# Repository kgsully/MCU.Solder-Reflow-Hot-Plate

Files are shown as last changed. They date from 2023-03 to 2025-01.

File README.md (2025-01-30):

# Solder Reflow Hot Plate
 ATMEGA328P-AU Based Solder Reflow Hot Plate Design.

 Please refer to the README docx or PDF found in the documentation folder for further information.
 
 Schematics and drawings may be found within the documentation folder (dimensions are in mm). 
 
 3D design / printing models are located under the 'Enclosure' folder.

 Imgur

 Imgur

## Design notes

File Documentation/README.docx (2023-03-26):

Solder Reflow Hot Plate

Rev 1.1

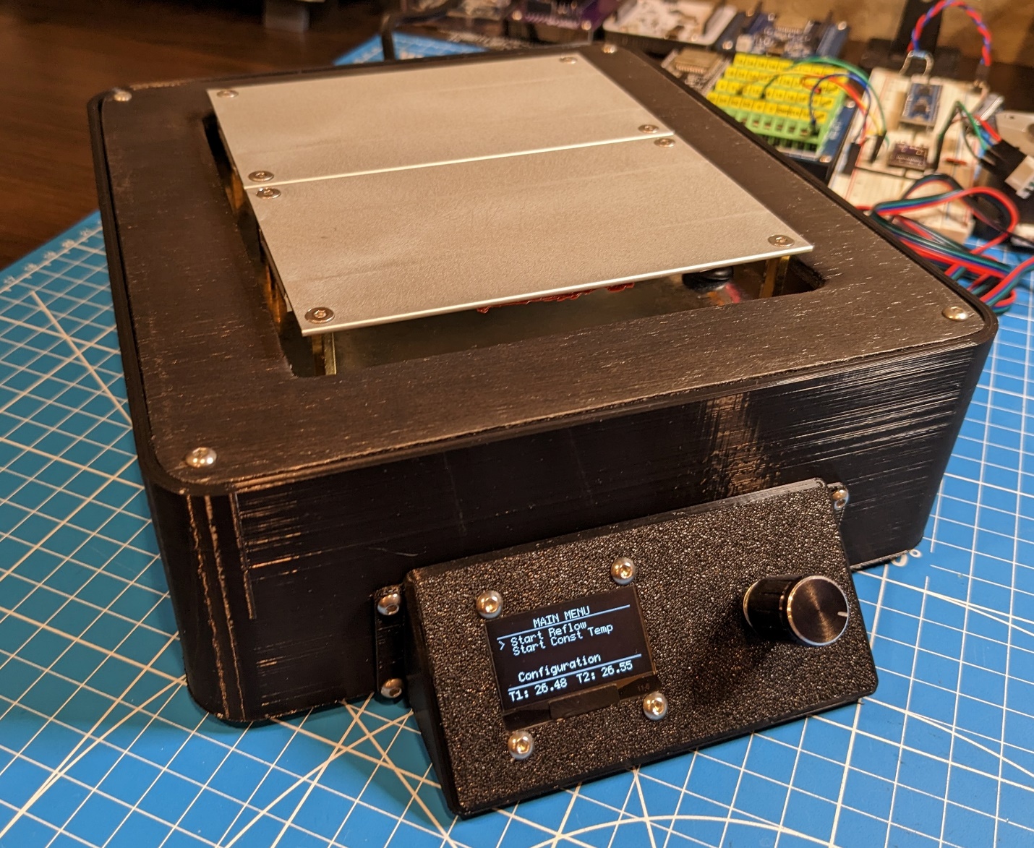
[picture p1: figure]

Ken S. 03/2023

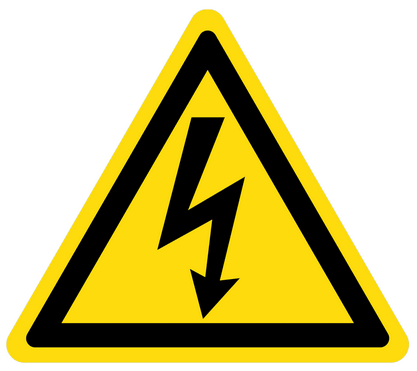
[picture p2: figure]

DANGER!

This project uses mains voltage to power portions of the circuit and the heating elements in the hot plates. This represents an electric shock hazard that can cause serious injury or death. Take appropriate care and do not attempt if you are not comfortable with or qualified to work with mains voltage.

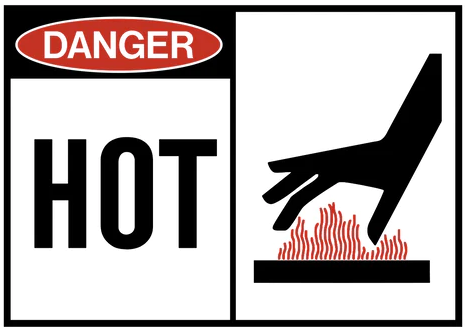
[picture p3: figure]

DANGER!

The heating plates used in this project can exceed 200°C and present burn and fire risks.

# 1. Description

This is an ATMEGA328P-AU based design for a solder reflow hot plate to be used for soldering SMD components onto custom PCBs. The microcontroller uses 2 PID loops to individually control the temperature for 2 aluminum heating plates. An OLED display and rotary encoder with push button allow the user to configure various parameters (reflow profile, PID tuning constants for the hot plate PID loops, etc), save the configuration to the microcontroller EEPROM memory, and start the unit in either constant temperature mode, or reflow profile mode.

Design files are included for the following:

1. Controller Electrical Schematic (w/ manufacturer and P/N component properties)
2. Controller PCB Layout
3. Interactive PCB Bill of Materials (BOM) – HTML format
4. Arduino IDE & PlatformIO based code
5. 3D Printed Enclosure
6. Sheet metal hot plate base
7. Wood cover plate

# 2. Electrical / PCB

The controller PCB uses zero crossing optocouplers / TRIACs to convert the PWM outputs from the microcontroller and regulate the input AC power used to drive the hot plates to a specified setpoint temperature.

A DIP socket is suggested to be used between the Optocoupler TRIACS (U10 & U20) and the PCB. This is not listed as an item in the BOM.

Please note that the following fuses are required, but not listed –

1. QTY 1 – 5x20mm 1A Time Delay Fuse (for AC / DC Converter)
2. QTY 2 – 5x20mm 4A Fast Acting Fuse (1 for each hot plate output, assumes 120VAC, amperage will need to be changed for 240VAC)

This design uses a Cypress / Infineon CY7C65213-28PVXI USB – UART bridge IC. The newer CY7C65213A-28PVXI may be used in its place. Please use the configuration utility that can be found at the following URL along with the included configuration file to program the USB – UART bridge:

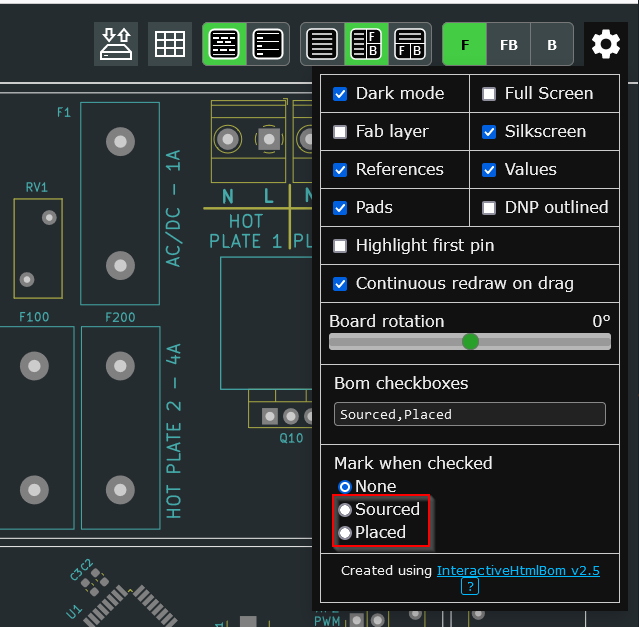
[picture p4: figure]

https://www.infineon.com/cms/en/design-support/tools/configuration/usb-uart-config-utility/

Please refer to the included electrical schematic / PCB design / interactive BOM (html format) for further details. Note that selection of one of the options shown in the screenshot of the interactive BOM may be helpful during PCB assembly –

Completed PCB Pictures:

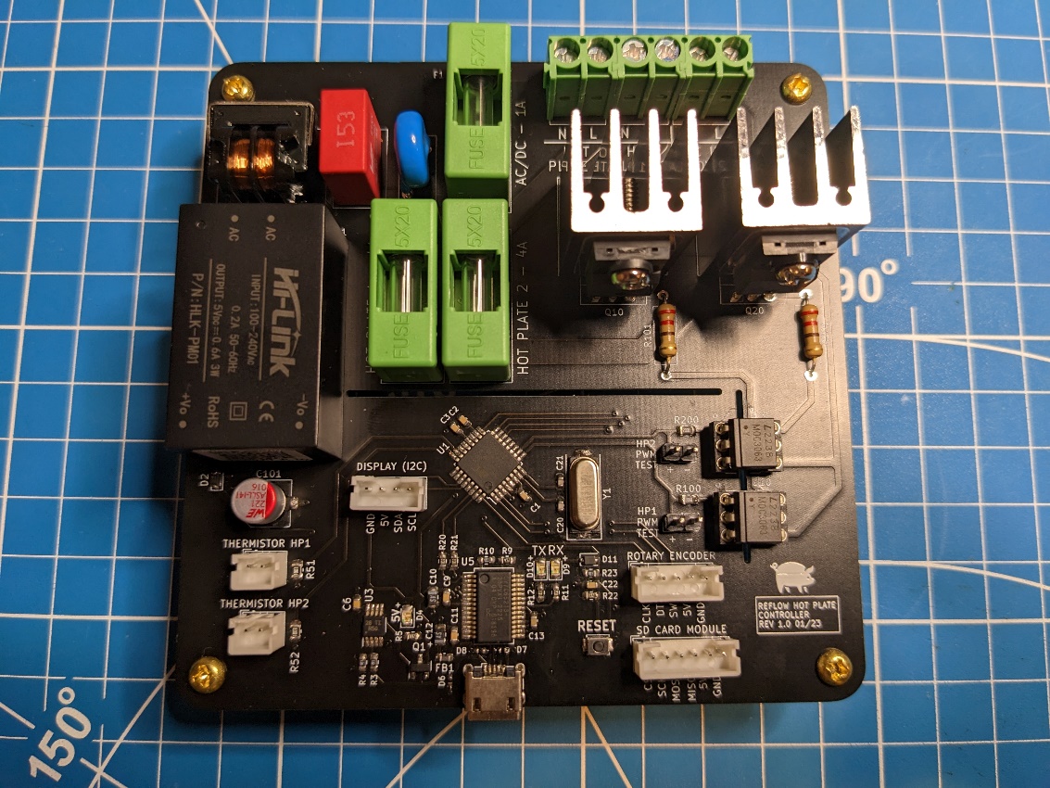
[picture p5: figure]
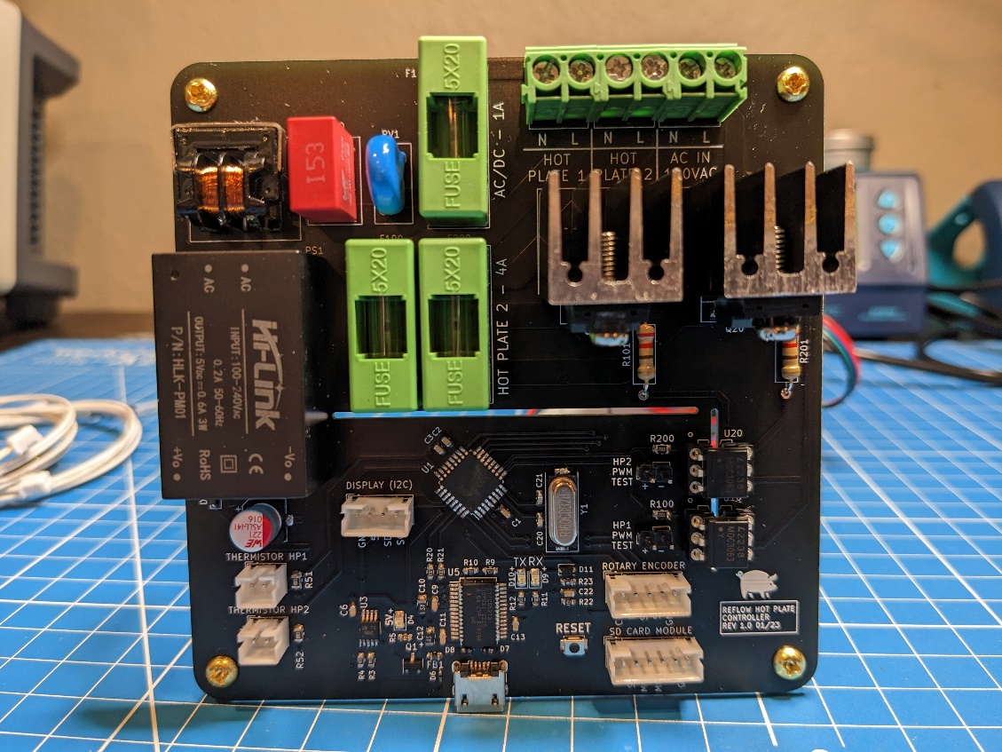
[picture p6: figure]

# 3. Assembly / Construction

Please refer to the included design files for assembly / construction details. Various format 3D models (STEP, F3D, and STL) are included, along with assembly drawings, and detail drawings for non-3D printed enclosure components.

IMPORTANT: Attach ground terminal / lead from AC receptacle so that it has electrical conductivity with hot plates! This is a REQUIRED safety measure to prevent electrical shock.

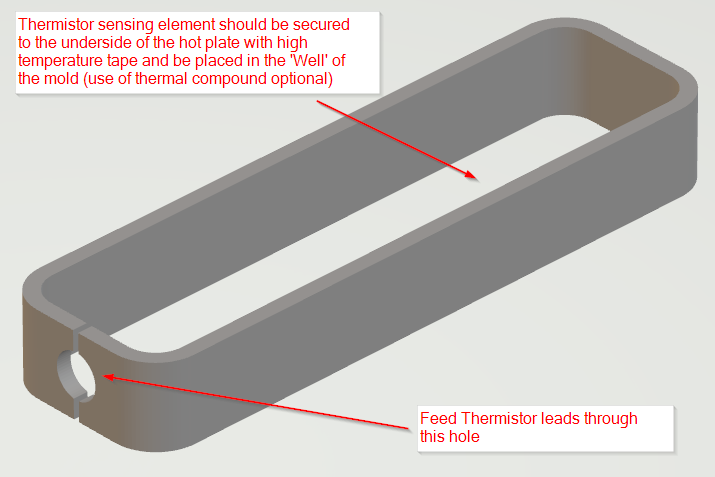
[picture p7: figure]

NOTE: The ‘Thermistor Silicon Mold’ model can be 3D printed and used as an aid to secure the thermistors to the underside of the heating plates.

Thermal compound can be applied to the underside of the hot plate and the thermistor sensing element set inside of it. High temperature tape is then used to secure the thermistor to the plate. Excess tape should be cut away. The ‘Thermistor Silicon Mold’ can then be set in place and be temporarily secured so that high temperature silicon may be applied to fill the mold ‘well’ and ensure the thermistors remain in place.

# 4. Microcontroller Code

Either the Arduino IDE or VS Code / PlatformIO may be used to upload the code to the microcontroller (both variants are included).

The code uses the following libraries:

1. Wire.h – Included in IDE by default
2. EEPROM.h – Included in IDE by default
3. PID_v1.h – PID by Brett Beauregard (v1.1.1)
4. U8g2lib.h – U8g2 by oliver (v2.33.15)

The U8g2lib object is configured in the included code to be used with an SH1106 based 128 x 64 OLED display. If the OLED display being used differs, this object will need to be reconfigured.

The code includes thermistor failure / thermal runaway protection. If either of the thermistors reads < -20°C, or the same measurement is read 3 consecutive times, heating is disabled and a thermistor failure message is presented on the display.

Configured reflow profile parameters and PID tuning constants are read from the microcontroller EEPROM at boot, and can be saved to the EEPROM by user selection of the ‘Save Configuration’ menu option. Note that the first time the controller board boots after the code is uploaded, default values may be present in the EEPROM. If this is the case, please refer to the code for default values for reflow profile / PID tuning parameters. Default reflow profile parameters are applicable to the reflow curve of the solder paste listed in the comments. Default PID tuning constants are a starting point – the PID loops will need to be tuned to the individual components for each build.

In reflow profile heating mode, the code is configured to take an initial snapshot of the hot plate temperatures and ramp the setpoint from the initial snapshot value to the programmed setpoint over the configured time. This is designed to ‘smooth’ the PID response to the heating curve. This can result in some initial lag when the setpoint starts to change, but helps to prevent overshoot / oscillation when compared with a step change in the temperature setpoint. It also allows the temperature to increase according to an implied ramp rate.

In constant temperature heating mode, the user sets the desired setpoint and the system interprets this as a step change.

# 5. Operation / Usage

Use / configuration of the reflow hot plate is achieved by use of the rotary encoder and display menu system. Rotation of the encoder changes the current selection and depressing the encoder knob selects the currently indicated option.

## 5.1. Menus

The currently selected menu item is indicated / denoted by the ‘>’ character appearing at the left of the menu item.

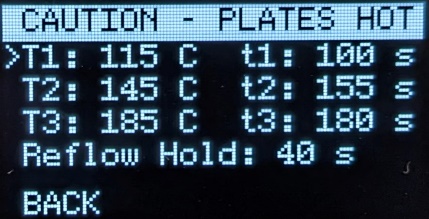
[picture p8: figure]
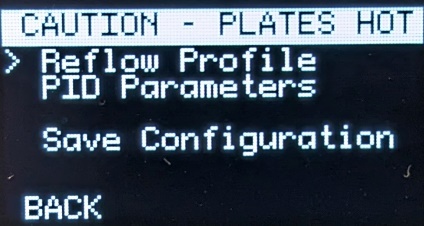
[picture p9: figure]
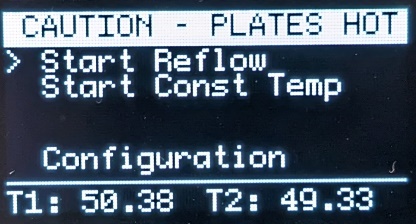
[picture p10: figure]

Note – If either of the hot plate temperatures exceed the programmed setpoint value (40°C), the top banner will change to display a high contrast ‘Caution – Plates Hot’ message.

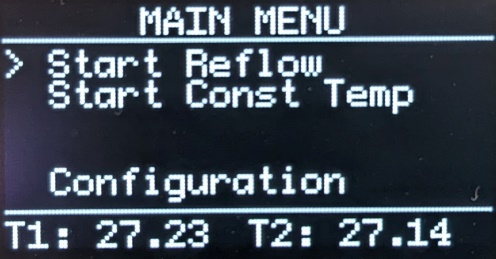
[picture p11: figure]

Main Menu – Used to start Reflow Profile / Constant Temperature heating modes / enter the configuration menu. This menu will also display the current hot plate temperatures at the bottom of the screen.

Start Reflow – Used to start the unit in ‘Reflow Profile’ heating mode. This mode uses the parameters set in the ‘Reflow Profile’ configuration menu and will automatically vary the temperature over time to attempt to coincide with the reflow curve. Upon selection of this menu option, the user is presented with a confirmation to start. The default selection is ‘No’ to prevent unintended start of reflow heating mode.

When reflow heating mode is running, the user is presented with information pertaining to which section of the reflow profile curve the unit is currently in (RAMP, SOAK, REFLOW RAMP, REFLOW, COMPLETE), elapsed time, temperatures of the hot plates (T1 / T2) and the setpoint value (SP).

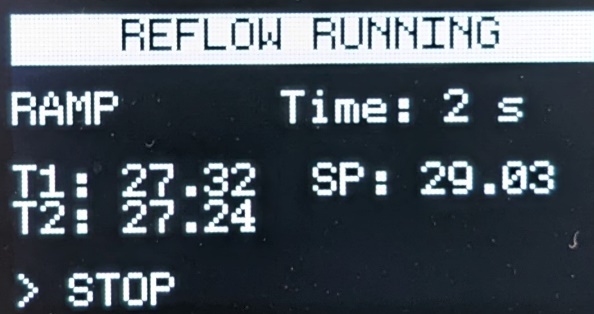
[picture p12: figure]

Selecting stop will prompt the user to confirm stopping the reflow heating mode.

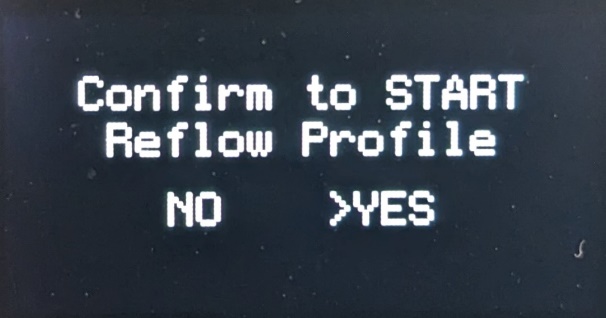
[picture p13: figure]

Start Constant Temp – Used to start the unit in ‘Constant Temperature’ heating mode. In this mode, the unit will heat the hot plates to a single specified temperature setpoint which won’t vary over time. When selected, the user is prompted to confirm start. Upon entering constant temperature heating mode for the first time, the temperature setpoint is set artificially low (default is 35°C) for safety reasons, and the user must select the ‘SP’ menu item, and change to the desired temperature setpoint.

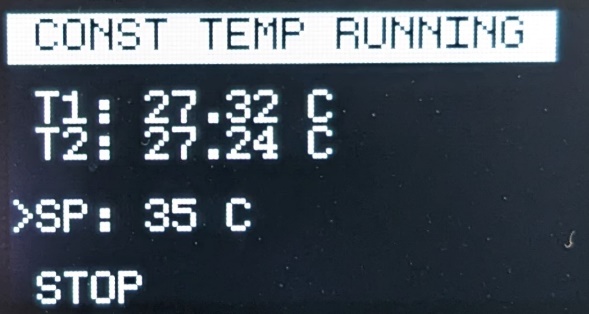
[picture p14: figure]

Selecting stop will prompt the user to confirm stopping the constant temperature heating mode.

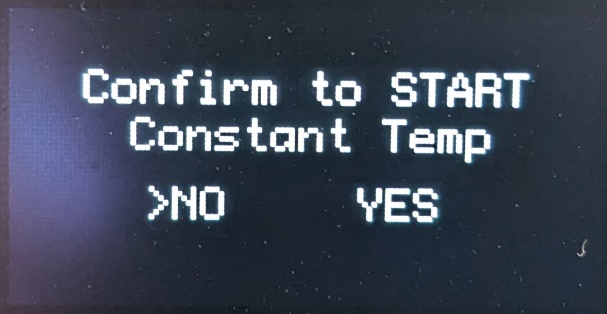
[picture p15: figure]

Configuration Menu – Used to select which configuration parameters to view / modify. The Main menu can be accessed by selecting ‘Back’.

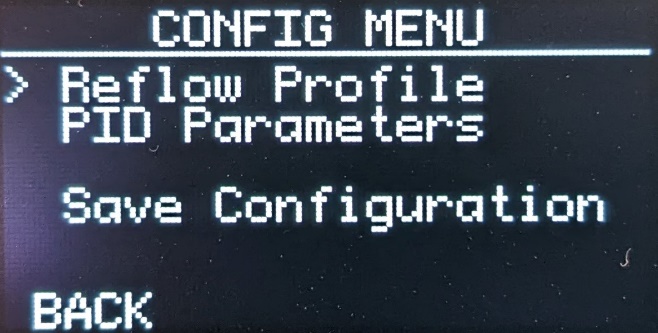
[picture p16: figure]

Reflow Profile – This menu allows the user to configure the reflow heating profile. Temperature setpoints are indicated by ‘uppercase’ T and time setpoints are indicated by ‘lowercase’ t. Selecting a menu item will draw a rectangle around the selected parameter, at which point the value can be changed. Pressing the rotary encoder will set the parameter value.
The Configuration Menu can be accessed by selecting ‘Back’.

Please refer to the following diagram for further explanation regarding reflow profile setpoints. Note that t1 through t3 are times along the X axis of the profile curve, and the reflow hold is a duration.

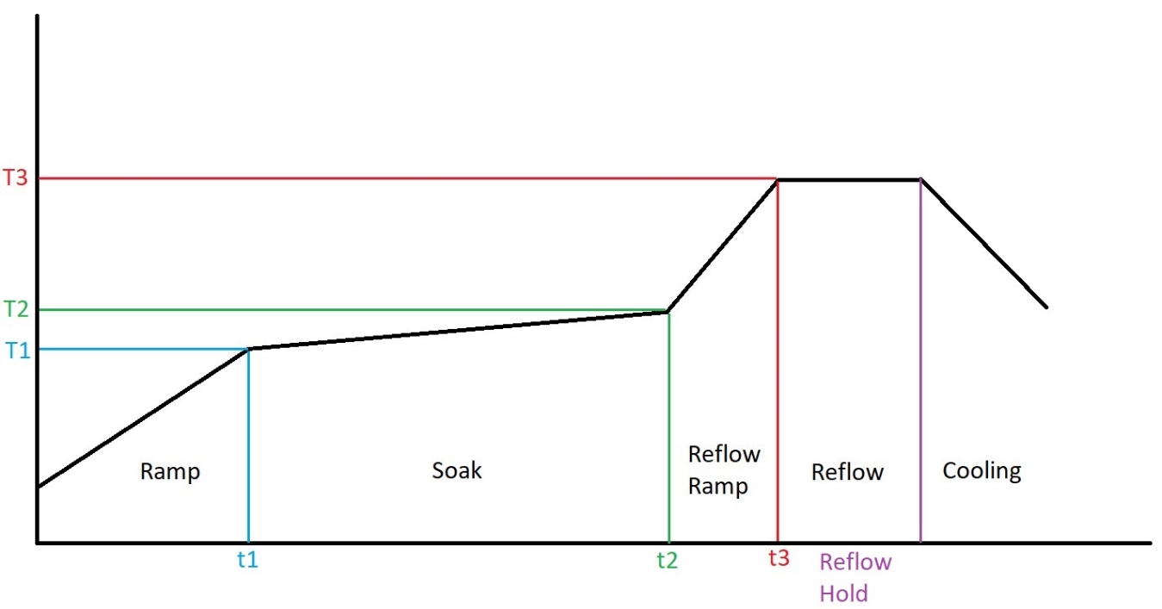
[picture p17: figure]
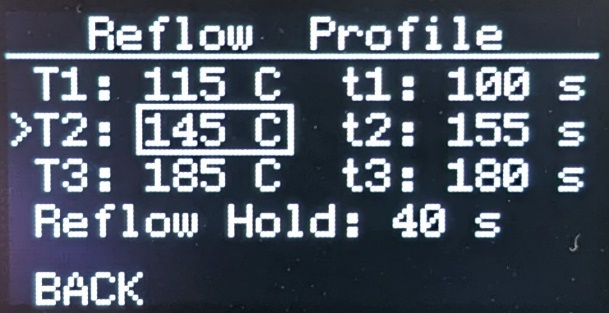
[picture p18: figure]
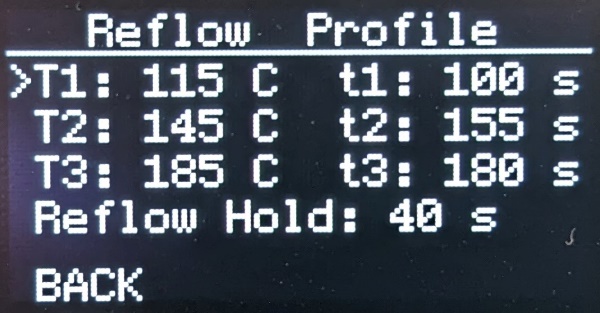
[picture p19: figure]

PID Parameters – This menu allows the user to configure the PID tuning constants for the 2 hot plate PID loops. Selecting a menu item will draw a rectangle around the selected parameter, at which point the value can be changed. Pressing the rotary encoder will set the parameter value.
Default PID tuning constants are intended to be a starting point. The hot plate PID loops will need to be tuned for each individual build as component performance / responses can vary.

The Configuration Menu can be accessed by selecting ‘Back’.

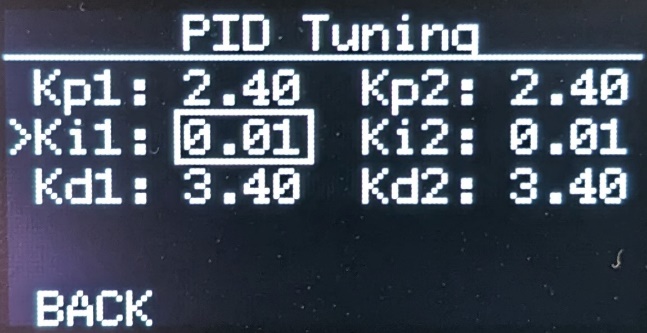
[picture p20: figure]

Save Configuration – Selecting this menu option will write the values of the reflow profile parameters and PID tuning constants to the microcontroller EEPROM. When selected, the user is presented with a message to indicate settings are being saved. Once complete, the display returns to the configuration menu screen.

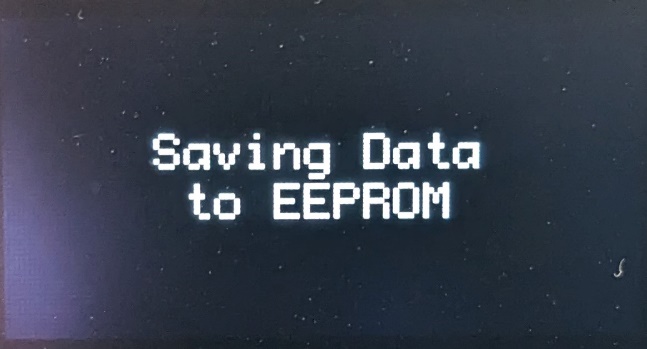
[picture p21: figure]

# 6. Addendum

Links / Part Numbers for various off-board / supporting parts:

AC SOCKET:
250V / 10A, 3 PIN IEC320 C14 MALE
https://www.amazon.com/dp/B0BCYYNRGP?psc=1&ref=ppx_yo2ov_dt_b_product_details

TO-220 TRIAC HEATSINK / HARDWARE:
HEATSINK - RADIOSHACK 2761368
MOUNTING HARDWARE - RADIOSHACK 2761373

HOT PLATES (QTY 2 PLATES REQ'D):
https://www.amazon.com/gp/product/B0BBGCKD5C/ref=ppx_yo_dt_b_search_asin_title?ie=UTF8&psc=1

ROTARY ENCODER MODULE:
https://www.amazon.com/gp/product/B07F26CT6B/ref=ppx_yo_dt_b_search_asin_title?ie=UTF8&psc=1

OLED SCREEN (SSD1106 VERSION):
https://www.amazon.com/gp/product/B08V97FYD2/ref=ppx_yo_dt_b_search_asin_title?ie=UTF8&psc=1

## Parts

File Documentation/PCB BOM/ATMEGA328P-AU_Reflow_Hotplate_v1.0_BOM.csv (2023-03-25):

Id | Designator | Package | Quantity | Designation | Supplier and ref
1 | R10,R4,R3,R23 | R_0603_1608Metric | 4 | 10k
2 | R200,R100 | R_0805_2012Metric | 2 | 200R
3 | F1 | WE 696106003002 | 1 | 1A
4 | C22,C1,C2,C3,C11,C9 | C_0603_1608Metric | 6 | 0.1u
5 | J10,J20 | JST_PH_B2B-PH-K_1x02_P2.00mm_Vertical | 2 | Conn_01x02_Male
6 | U3 | VSSOP-8_3.0x3.0mm_P0.65mm | 1 | LMV358IDGKR
7 | D10,D9 | LED_0805_2012Metric | 2 | GRN
8 | C10,C12 | C_0805_2012Metric | 2 | 4.7u
9 | U5 | SSOP-28_5.3x10.2mm_P0.65mm | 1 | CY7C65213-28PVXI
10 | H4,H2,H1,H3 | MountingHole_3.2mm_M3 | 4 | MountingHole
11 | R101,R201 | R_Axial_DIN0309_L9.0mm_D3.2mm_P12.70mm_Horizontal | 2 | 220R
12 | R11,R22,R5,R12,R21,R20 | R_0603_1608Metric | 6 | 1k
13 | C6 | C_0603_1608Metric | 1 | 100n
14 | C13 | C_0603_1608Metric | 1 | 1u
15 | J502 | JST_PH_B6B-PH-K_1x06_P2.00mm_Vertical | 1 | Conn_01x06_Male
16 | D8,D7,D6 | D_0402_1005Metric | 3 | 5VWM
17 | F100,F200 | WE 696106003002 | 2 | 4A
18 | J100,J200,J300 | TerminalBlock_Phoenix_MKDS-1,5-2_1x02_P5.00mm_Horizontal | 3 | 1935776
19 | C100 | C_Rect_L13.0mm_W8.0mm_P10.00mm_FKS3_FKP3_MKS4 | 1 | 0.1uF
20 | C21,C20 | C_0603_1608Metric | 2 | 22p
21 | J501 | JST_PH_B5B-PH-K_1x05_P2.00mm_Vertical | 1 | Conn_01x05_Male
22 | U20,U10 | DIP-6_W7.62mm | 2 | MOC3063M
23 | D11 | D_SOD-323 | 1 | 1N4148WS
24 | D4 | LED_0805_2012Metric | 1 | RED
25 | FB1 | L_0603_1608Metric | 1 | 40-100R
26 | Q10,Q20 | TO-220-3_Vertical | 2 | BT139X-600,127
27 | U1 | TQFP-32_7x7mm_P0.8mm | 1 | ATmega328P-AU
28 | RV1 | RV_Disc_D12mm_W5.8mm_P7.5mm | 1 | 10D561K
29 | R9 | R_0603_1608Metric | 1 | 4k7
30 | J201,J101 | PinHeader_1x02_P2.54mm_Vertical | 2 | Conn_01x02_Male
31 | R52,R51 | R_0805_2012Metric | 2 | 100k
32 | PS1 | Converter_ACDC_HiLink_HLK-PMxx | 1 | HLK-PM01
33 | FL1 | KEMET SU9H-R02140 | 1 | 14mH
34 | SW1 | SW_SPST_B3U-1000P | 1 | RESET
35 | J3 | USB_Micro-B_Wuerth_629105150521 | 1 | USB_B_Micro
36 | J500 | JST_PH_B4B-PH-K_1x04_P2.00mm_Vertical | 1 | Conn_01x04_Male
37 | Y1 | Crystal_SMD_HC49-SD | 1 | 16MHZ
38 | C101 | CP_Elec_6.3x5.9 | 1 | 220uF
39 | D2 | D_SOD-323 | 1 | BAT760-7
40 | Q1 | SOT-23 | 1 | DMP2110U-7

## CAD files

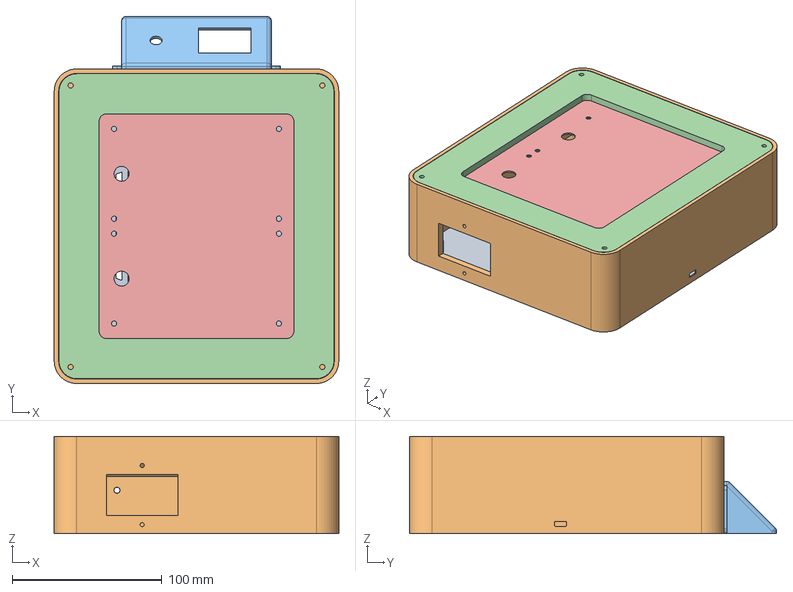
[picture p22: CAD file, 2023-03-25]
Enclosure/Model/Solder Reflow Hot Plate Enclosure Assembly.step
190.0 x 245.0 x 65.0 mm
Solder Reflow Hot Plate Base
Top Cover Plate_1
Hot Plate Mounting Plate_1

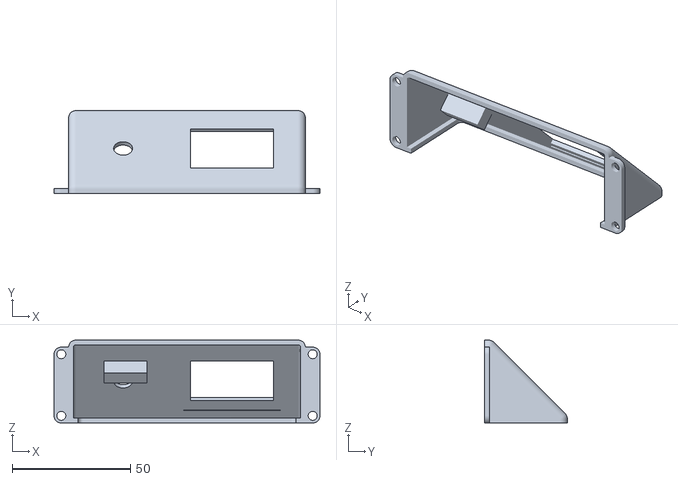
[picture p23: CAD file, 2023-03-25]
Enclosure/3D Printing/Control Enclosure/Model/Control Enclosure.stl
112.4 x 35.0 x 35.0

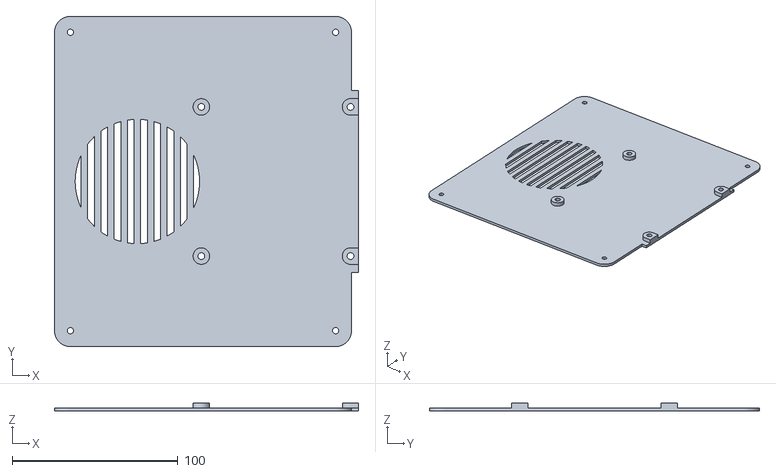
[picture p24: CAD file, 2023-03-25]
Enclosure/3D Printing/Enclosure Base/Model/Board Mount.stl
183.4 x 199.2 x 5.00

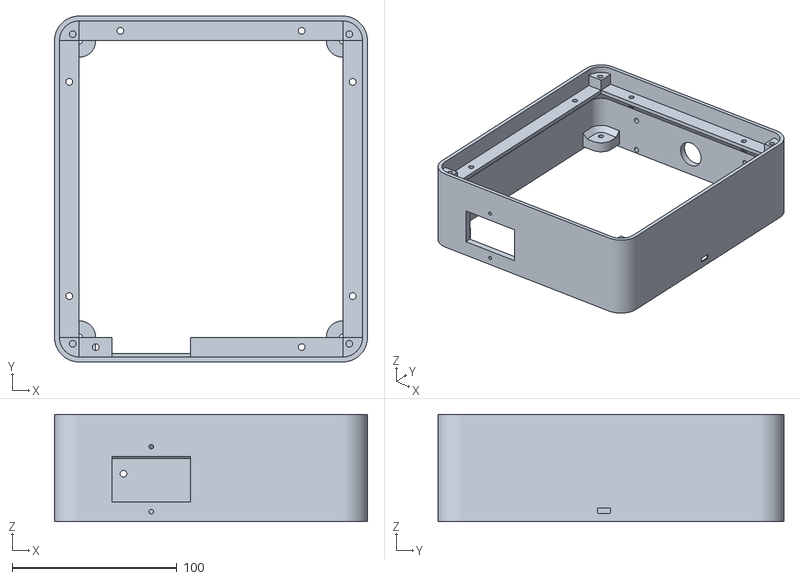
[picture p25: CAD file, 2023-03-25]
Enclosure/3D Printing/Enclosure Side Wall/Model/Sidewall.stl
190.0 x 210.0 x 65.0

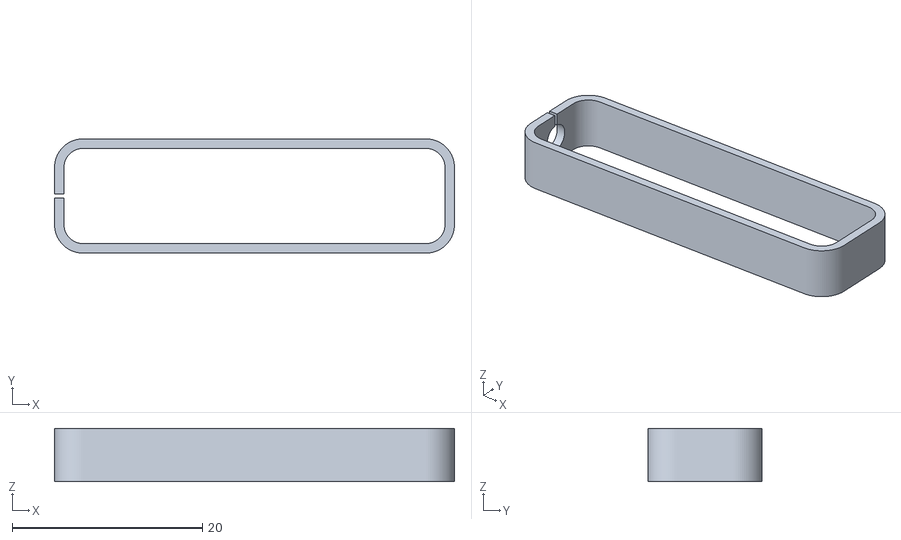
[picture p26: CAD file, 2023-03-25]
Enclosure/3D Printing/Thermistor Silicon Molds/Model/Thermistor SIlicon Mold.stl
42.0 x 12.0 x 5.60

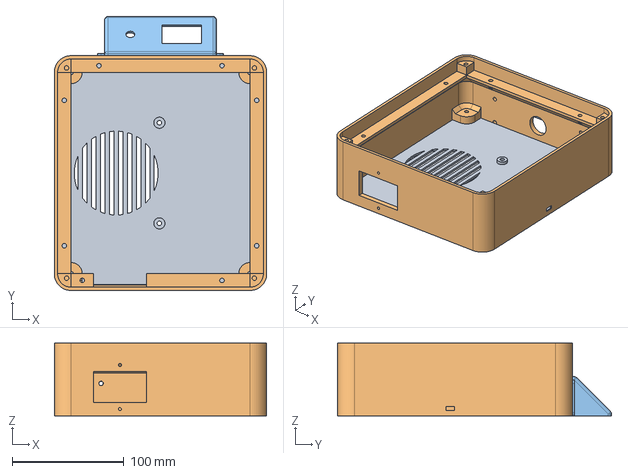
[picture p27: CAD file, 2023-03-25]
Enclosure/Model/Solder Reflow Hot Plate Base.step
190.0 x 245.0 x 65.0 mm

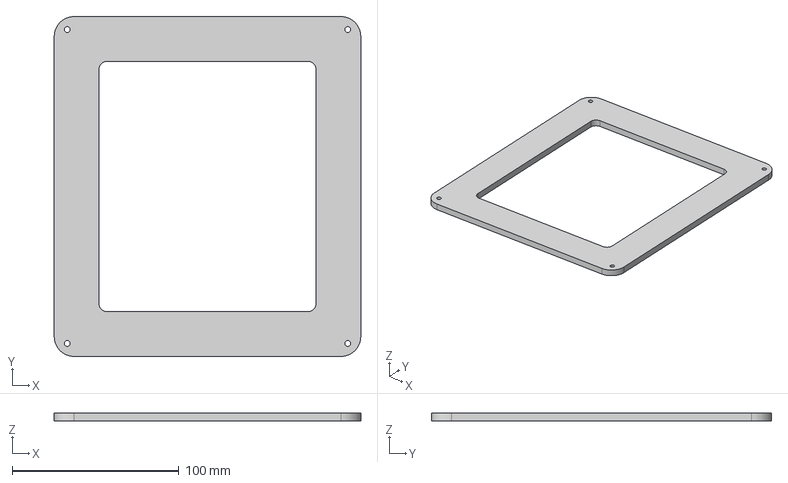
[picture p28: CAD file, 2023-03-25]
Enclosure/Model/Top Cover Plate.step
183.6 x 203.6 x 5.00 mm

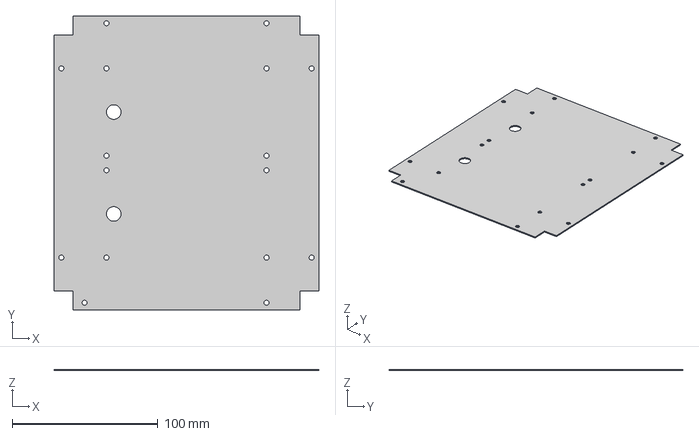
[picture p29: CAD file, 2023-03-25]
Enclosure/Model/Hot Plate Mounting Plate.step
182.0 x 202.0 x 1.00 mm

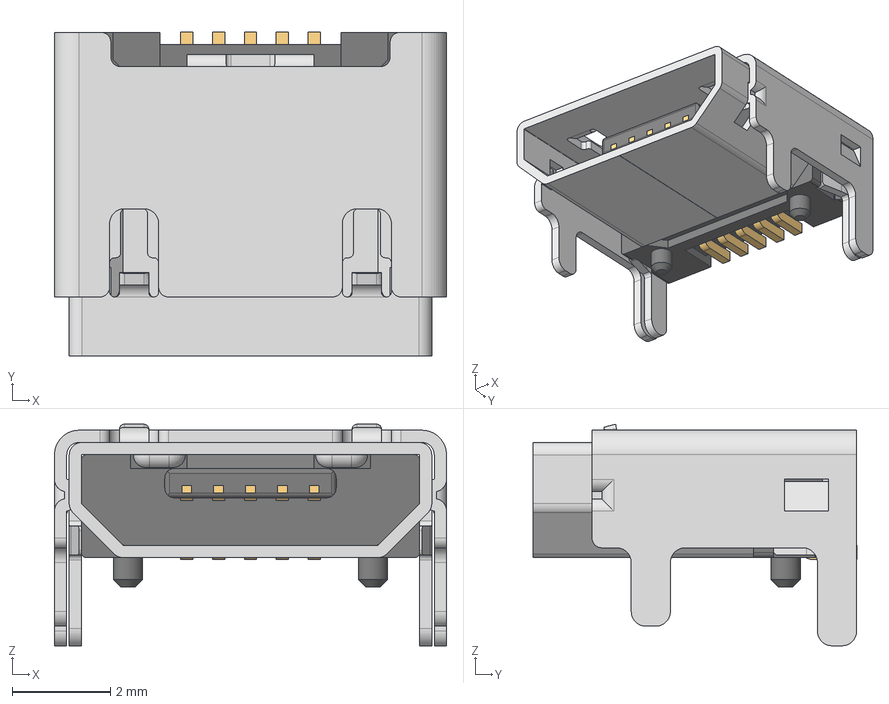
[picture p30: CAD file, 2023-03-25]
Electrical & PCB/Models/629105150521 (rev1).stp
8.00 x 6.60 x 4.52 mm
629105150521_Housing
629105150521_Pin1 x 4
629105150521_Pin2
629105150521_Shielding2
629105150521_Shielding

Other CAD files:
Enclosure/Model/Thermistor Silicon Mold.step
Enclosure/Model/Hot Plate Mounting Plate.f3d
Enclosure/Model/Solder Reflow Hot Plate Base.f3d
Enclosure/Model/Solder Reflow Hot Plate Enclosure Assembly.f3z
Enclosure/Model/Thermistor Silicon Mold.f3d
Enclosure/Model/Top Cover Plate.f3d

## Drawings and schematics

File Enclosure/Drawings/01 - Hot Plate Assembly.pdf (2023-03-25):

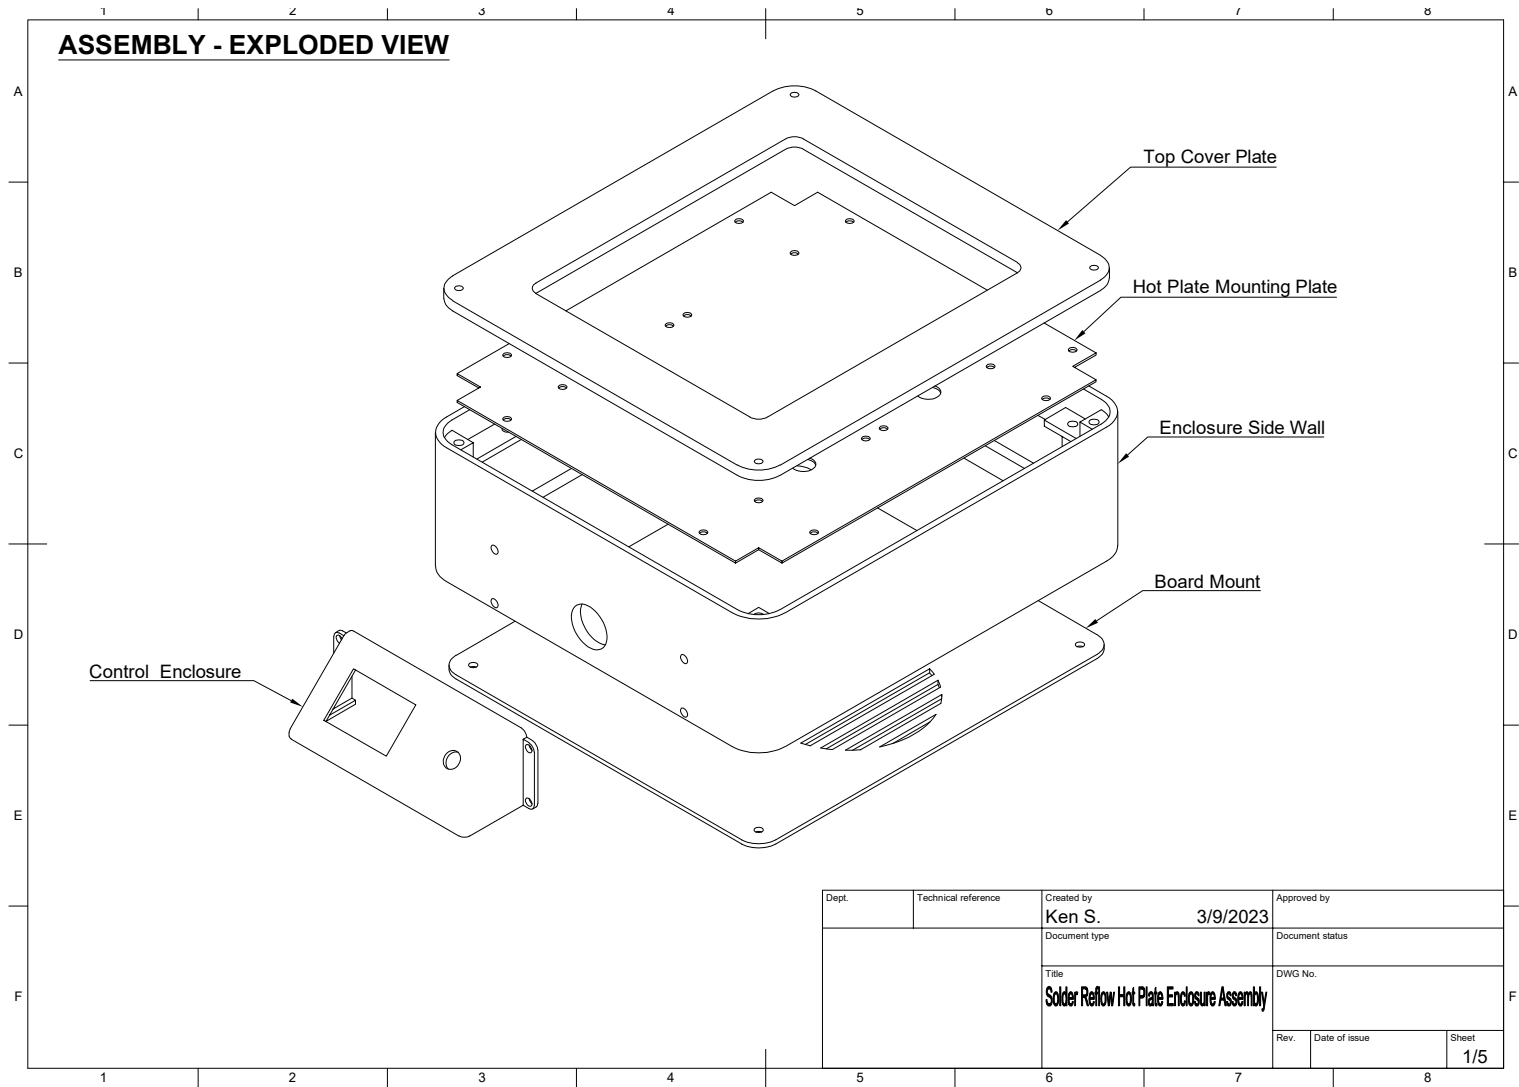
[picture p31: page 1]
8 BCDEF; ABCDEF Dept.; Technical reference; Created by; Approved by Document type; Document status Title; DWG No. Rev.; Date of issue; Sheet 3/9/2023; 1/5 Ken S.; Top Cover Plate Hot Plate Mounting Plate Enclosure Side Wall Control Enclosure; Board Mount ASSEMBLY - EXPLODED VIEW

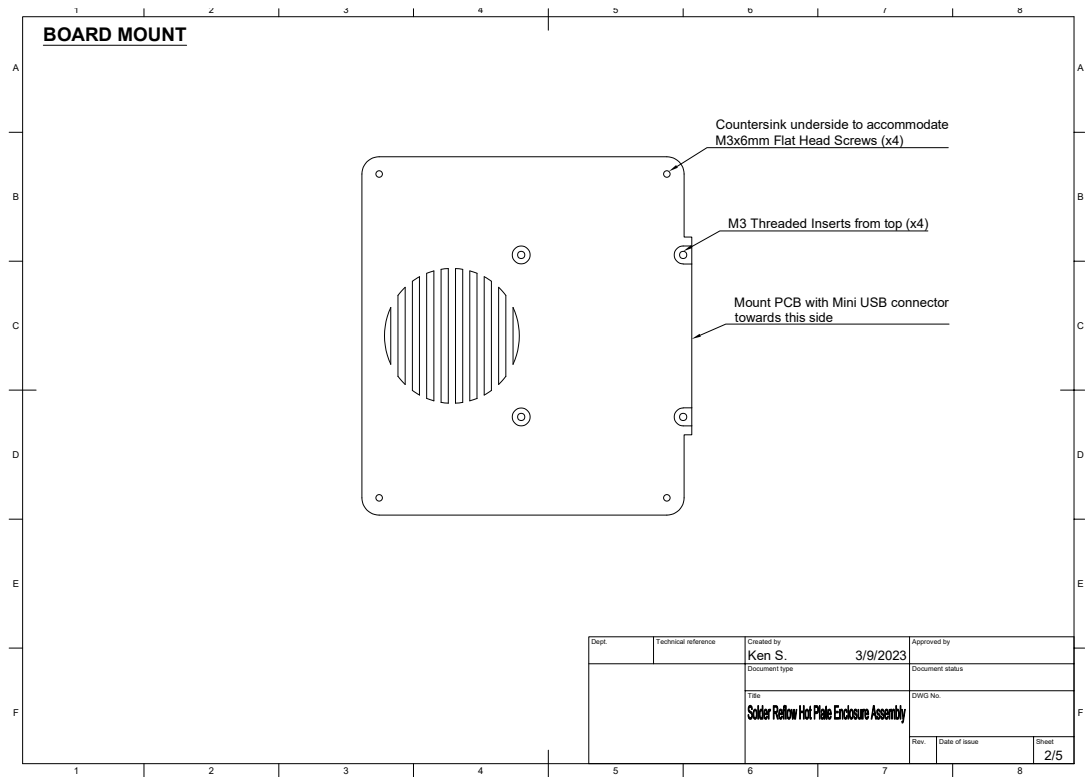
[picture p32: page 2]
8 BCDEF; ABCDEF Dept.; Technical reference; Created by; Approved by Document type; Document status Title; DWG No. Rev.; Date of issue; Sheet 3/9/2023; 2/5 Ken S. M3 Threaded Inserts from top (x4) Countersink underside to accommodate M3x6mm Flat Head Screws (x4) Mount PCB with Mini USB connector towards this side BOARD MOUNT

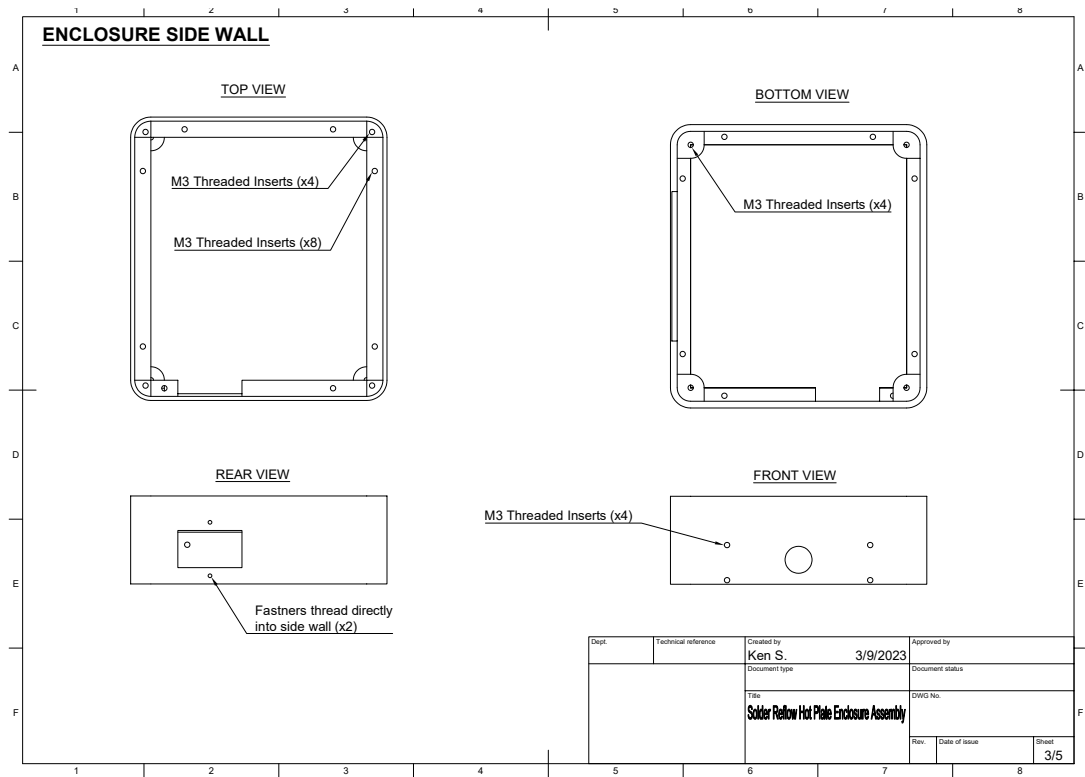
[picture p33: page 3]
8 BCDEF; ABCDEF Dept.; Technical reference; Created by; Approved by Document type; Document status Title; DWG No. Rev.; Date of issue; Sheet 3/9/2023; 3/5 Ken S. TOP VIEW M3 Threaded Inserts (x8) M3 Threaded Inserts (x4); BOTTOM VIEW M3 Threaded Inserts (x4) M3 Threaded Inserts (x4) Fastners thread directly into side wall (x2) REAR VIEW; FRONT VIEW ENCLOSURE SIDE WALL

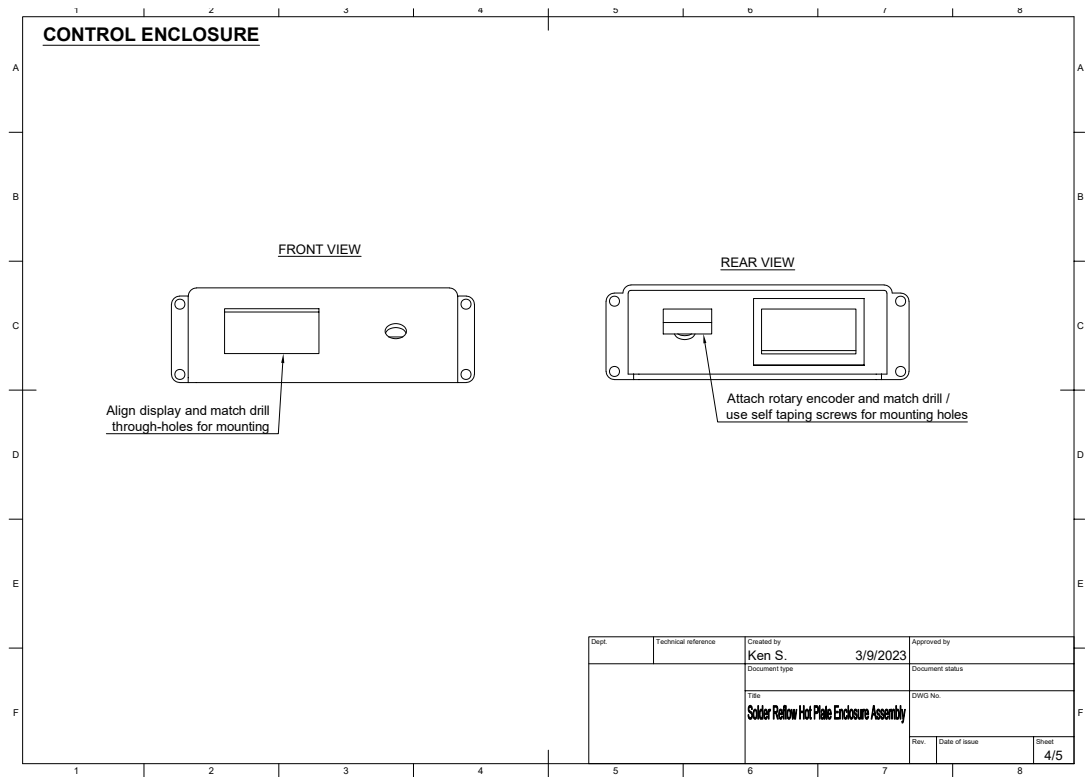
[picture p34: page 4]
8 BCDEF; ABCDEF Dept.; Technical reference; Created by; Approved by Document type; Document status Title; DWG No. Rev.; Date of issue; Sheet 3/9/2023; 4/5 Ken S. REAR VIEW FRONT VIEW Align display and match drill through-holes for mounting; Attach rotary encoder and match drill / use self taping screws for mounting holes CONTROL ENCLOSURE

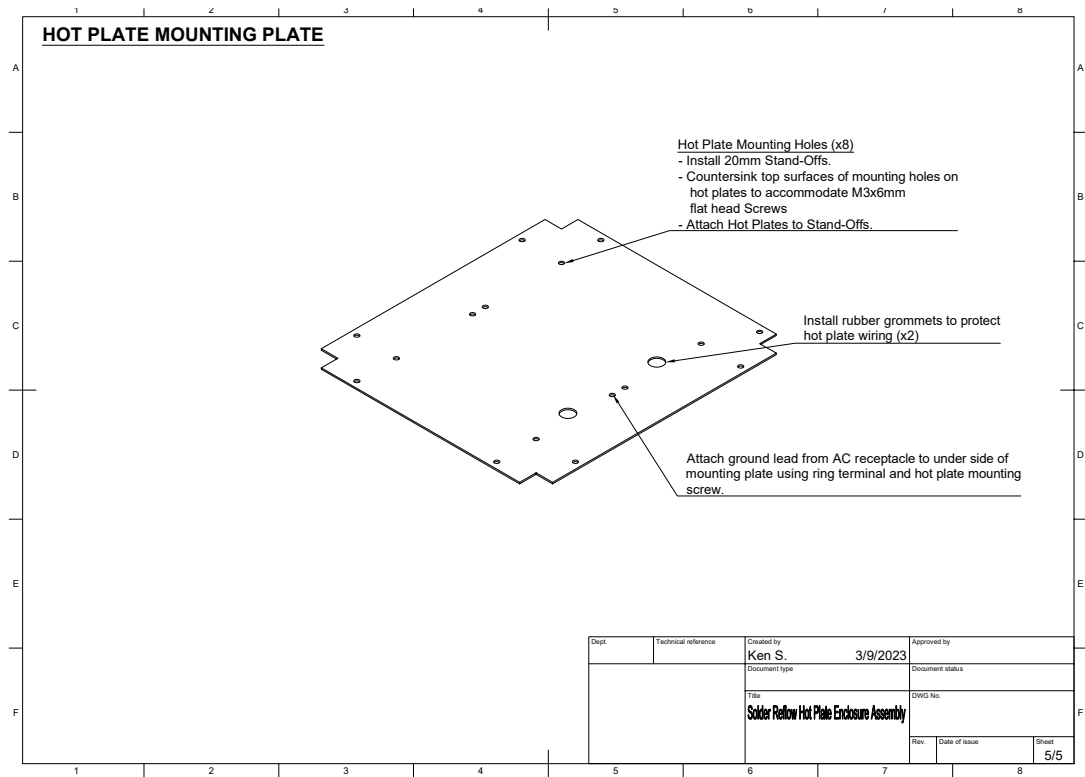
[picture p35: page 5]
8 BCDEF; ABCDEF Dept.; Technical reference; Created by; Approved by Document type; Document status Title; DWG No. Rev.; Date of issue; Sheet 3/9/2023; 5/5 Ken S. HOT PLATE MOUNTING PLATE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

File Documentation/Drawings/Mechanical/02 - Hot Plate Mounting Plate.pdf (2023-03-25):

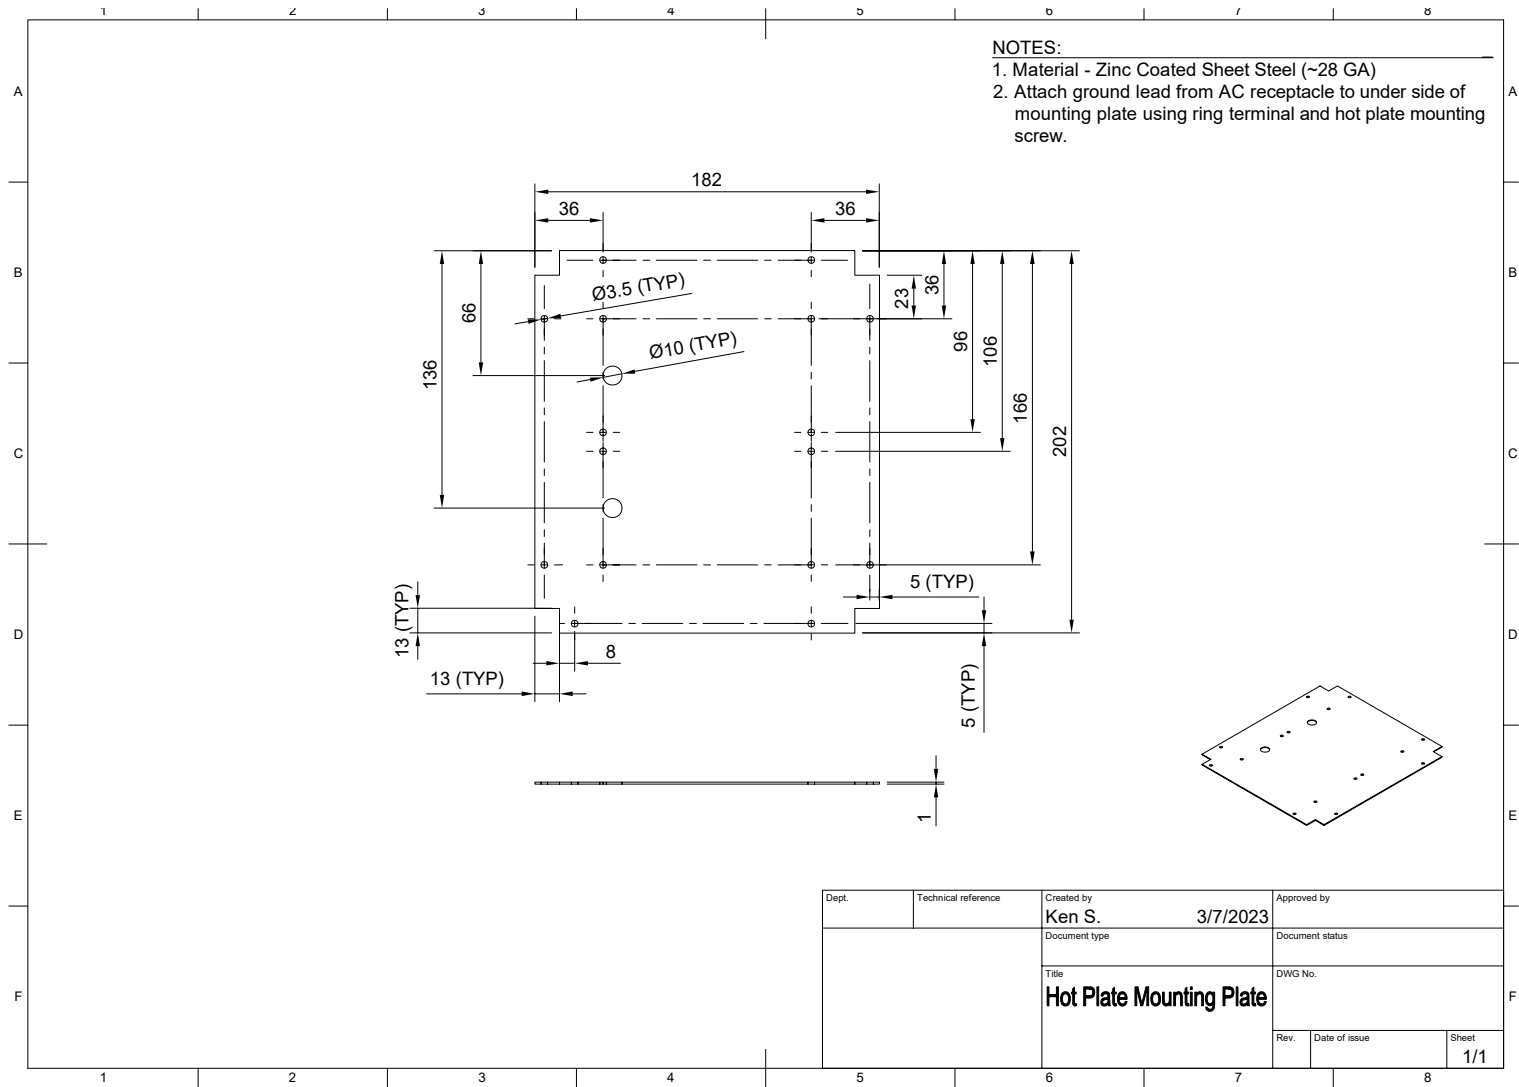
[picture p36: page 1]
8 BCDEF; ABCDEF Dept.; Technical reference; Created by; Approved by Document type; Document status Title; DWG No. Rev.; Date of issue; Sheet 3/7/2023; 1/1 Ken S. 182; 202 1 13 (TYP); 136 5 (TYP)5 (TYP)

166 36 36 NOTES: _ 1. Material - Zinc Coated Sheet Steel (~28 GA) 2. Attach ground lead from AC receptacle to under side of mounting plate using ring terminal and hot plate mounting screw.

13 (TYP) Ø3.5 (TYP) Ø10 (TYP) 66

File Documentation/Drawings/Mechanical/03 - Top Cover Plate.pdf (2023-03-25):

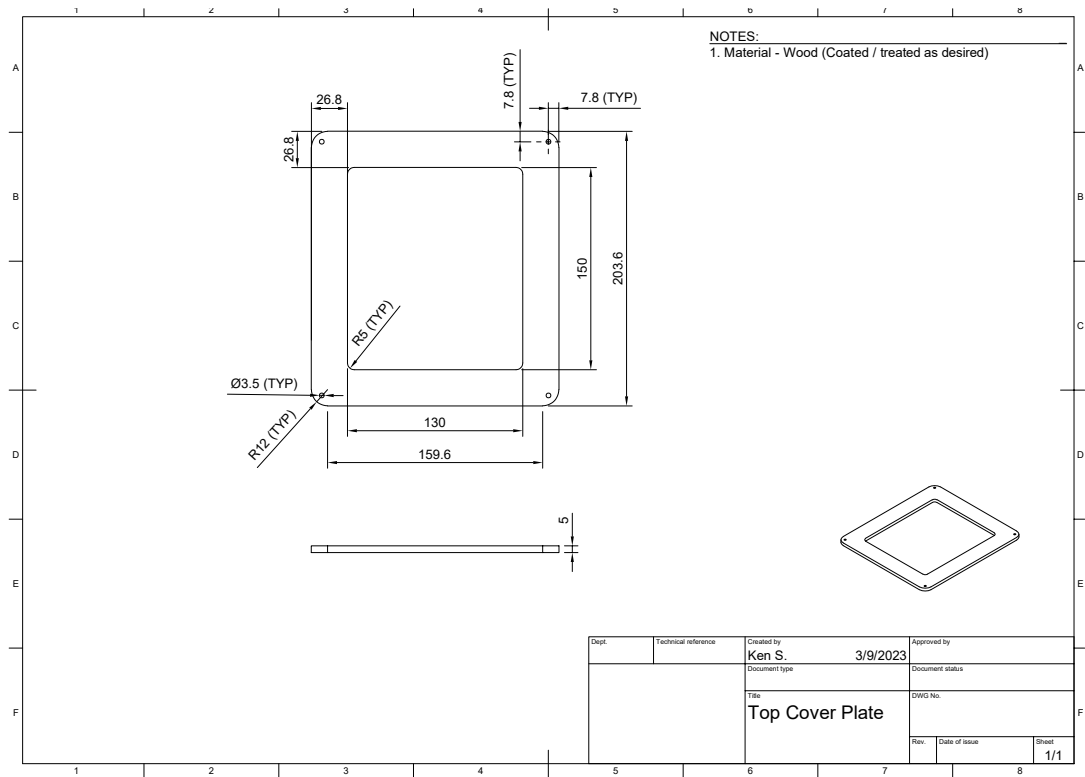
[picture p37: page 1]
8 BCDEF; ABCDEF Dept.; Technical reference; Created by; Approved by Document type; Document status Title; DWG No. Rev.; Date of issue; Sheet 3/9/2023; 1/1 Top Cover Plate Ken S. ⁵

7.8 (TYP) NOTES: _ 1. Material - Wood (Coated / treated as desired)

26.8 Ø3.5 (TYP) R12 (TYP) R5 (TYP) 7.8 (TYP)

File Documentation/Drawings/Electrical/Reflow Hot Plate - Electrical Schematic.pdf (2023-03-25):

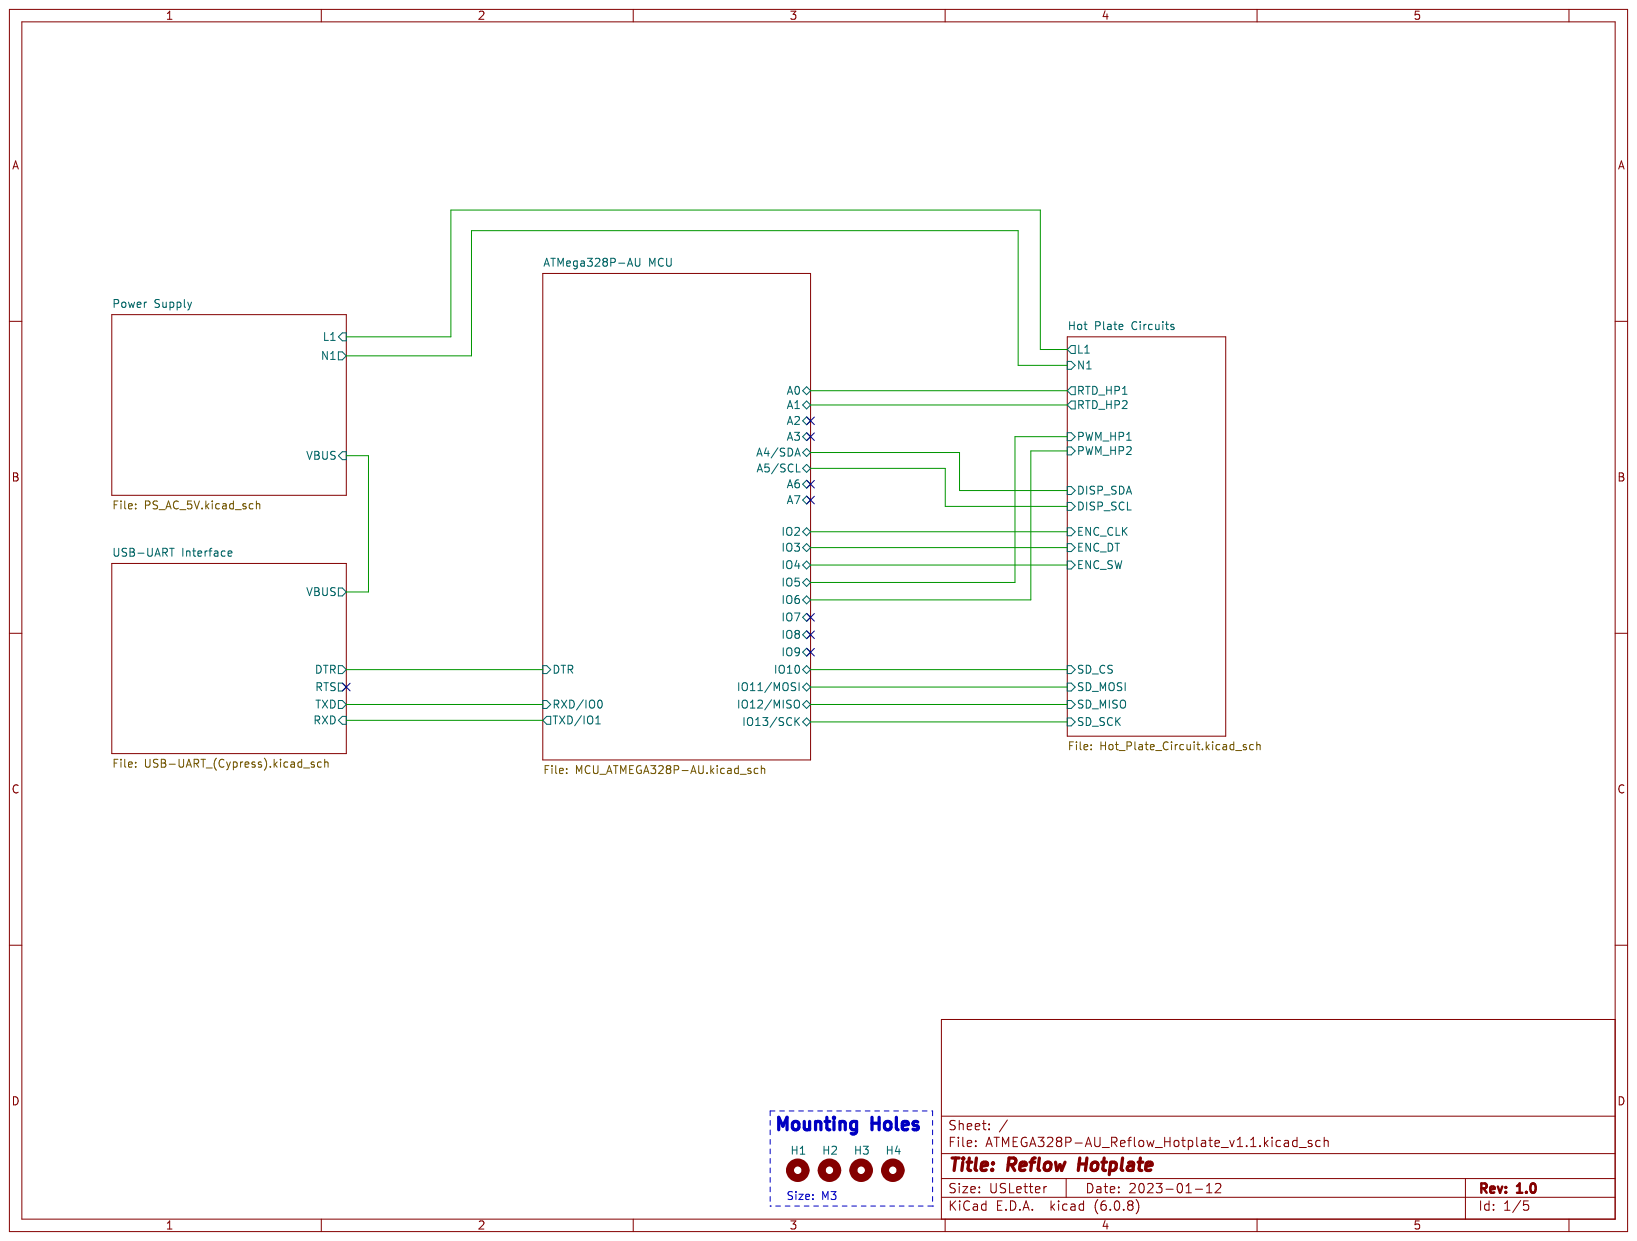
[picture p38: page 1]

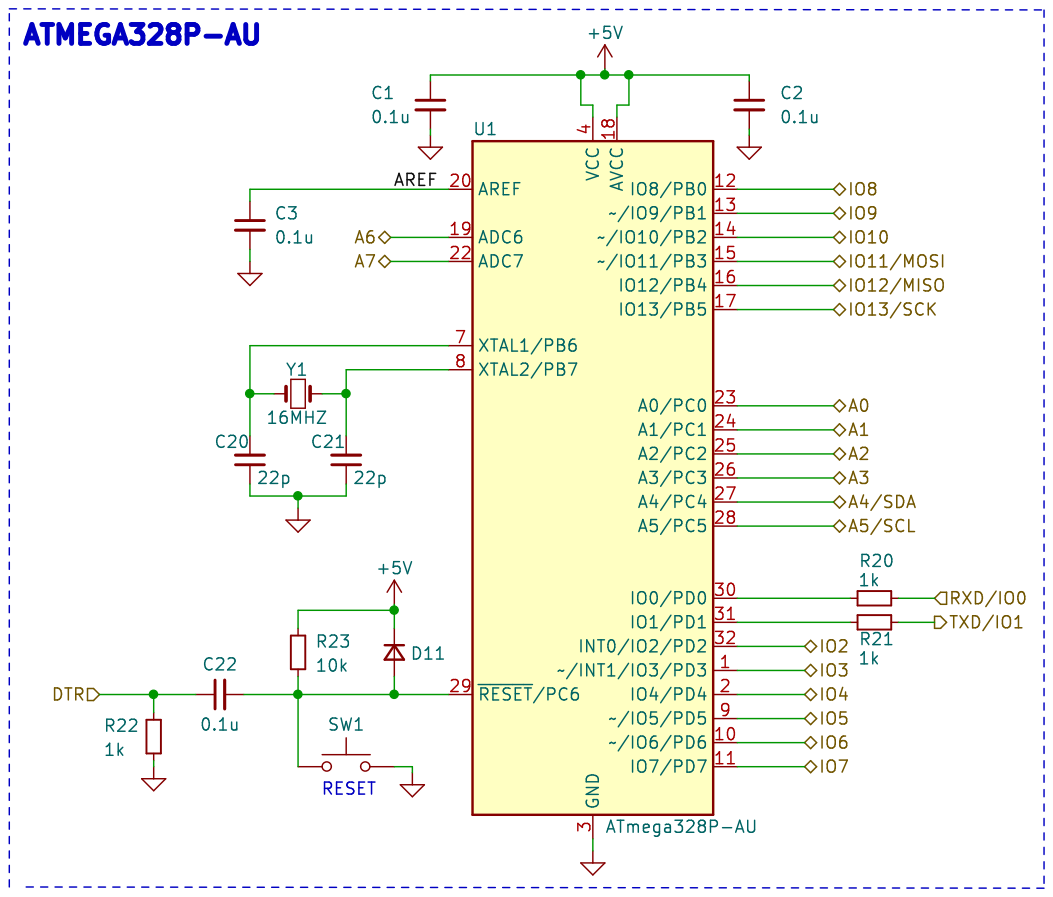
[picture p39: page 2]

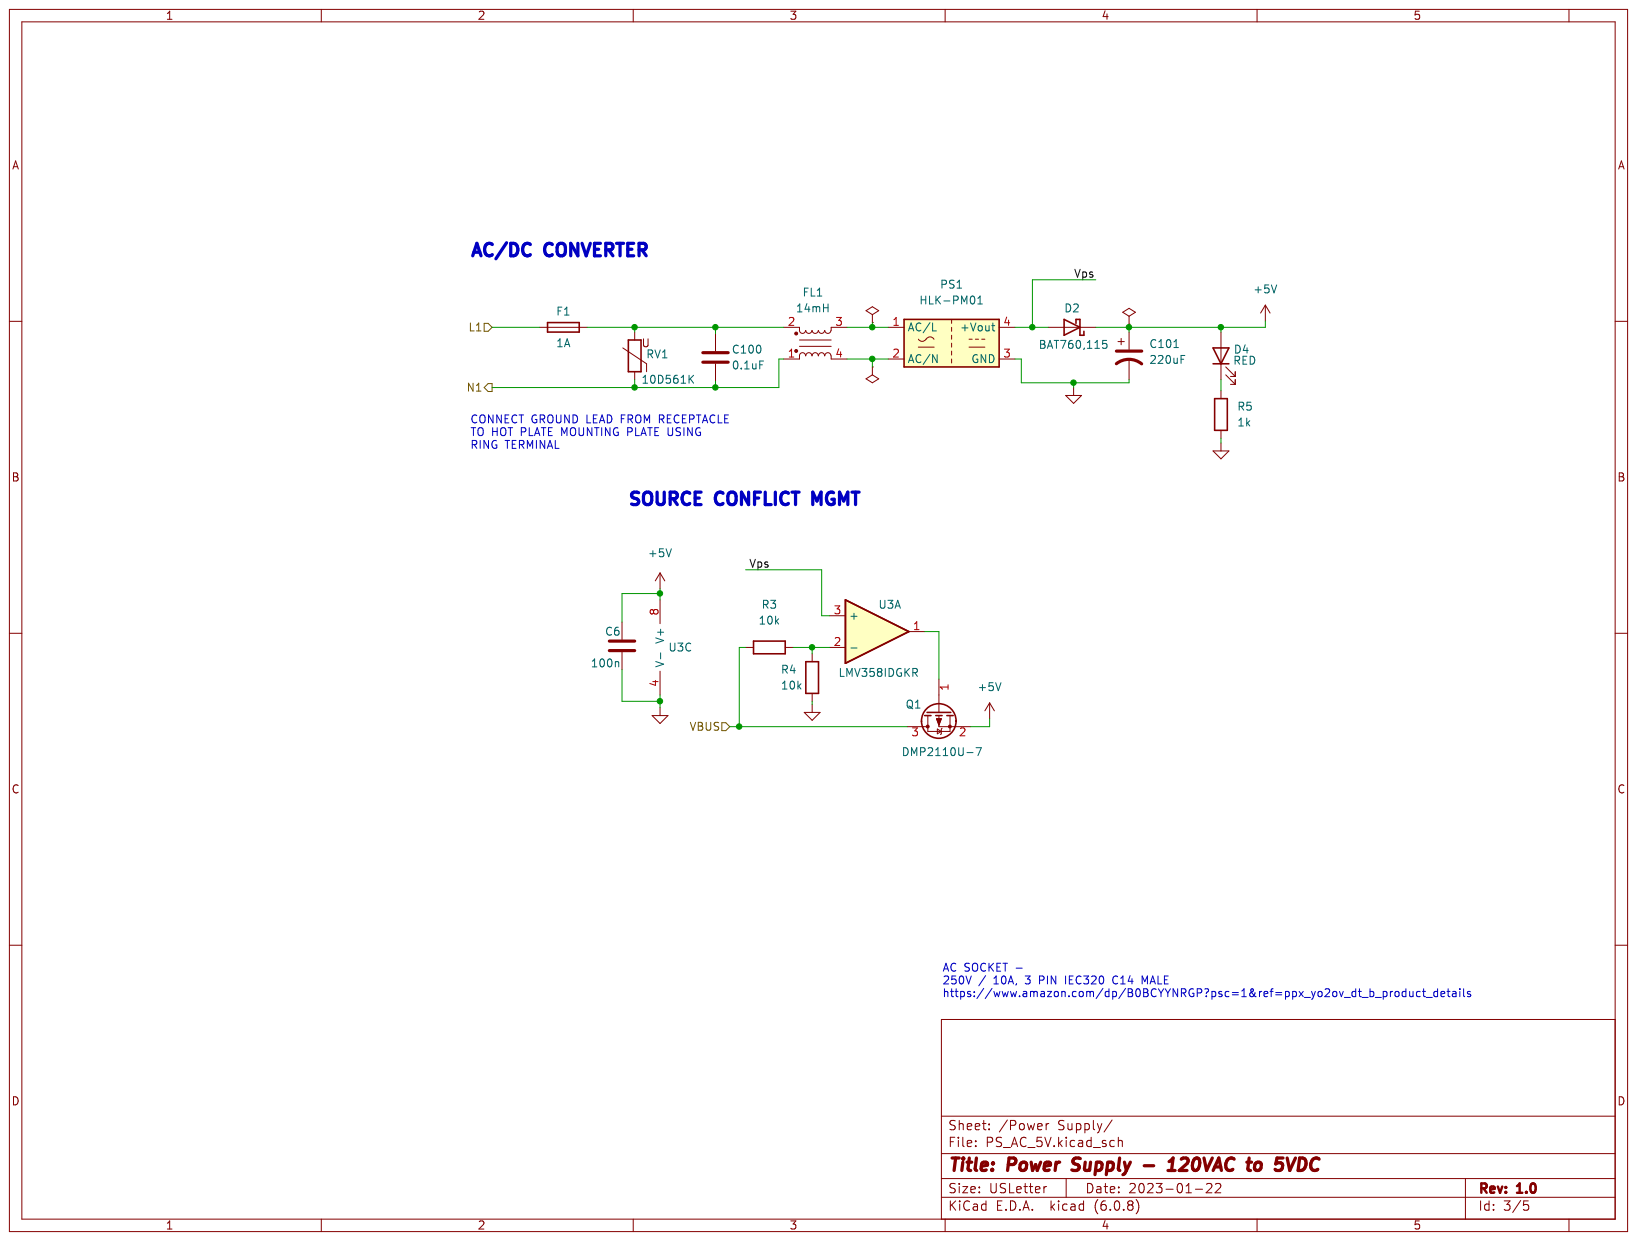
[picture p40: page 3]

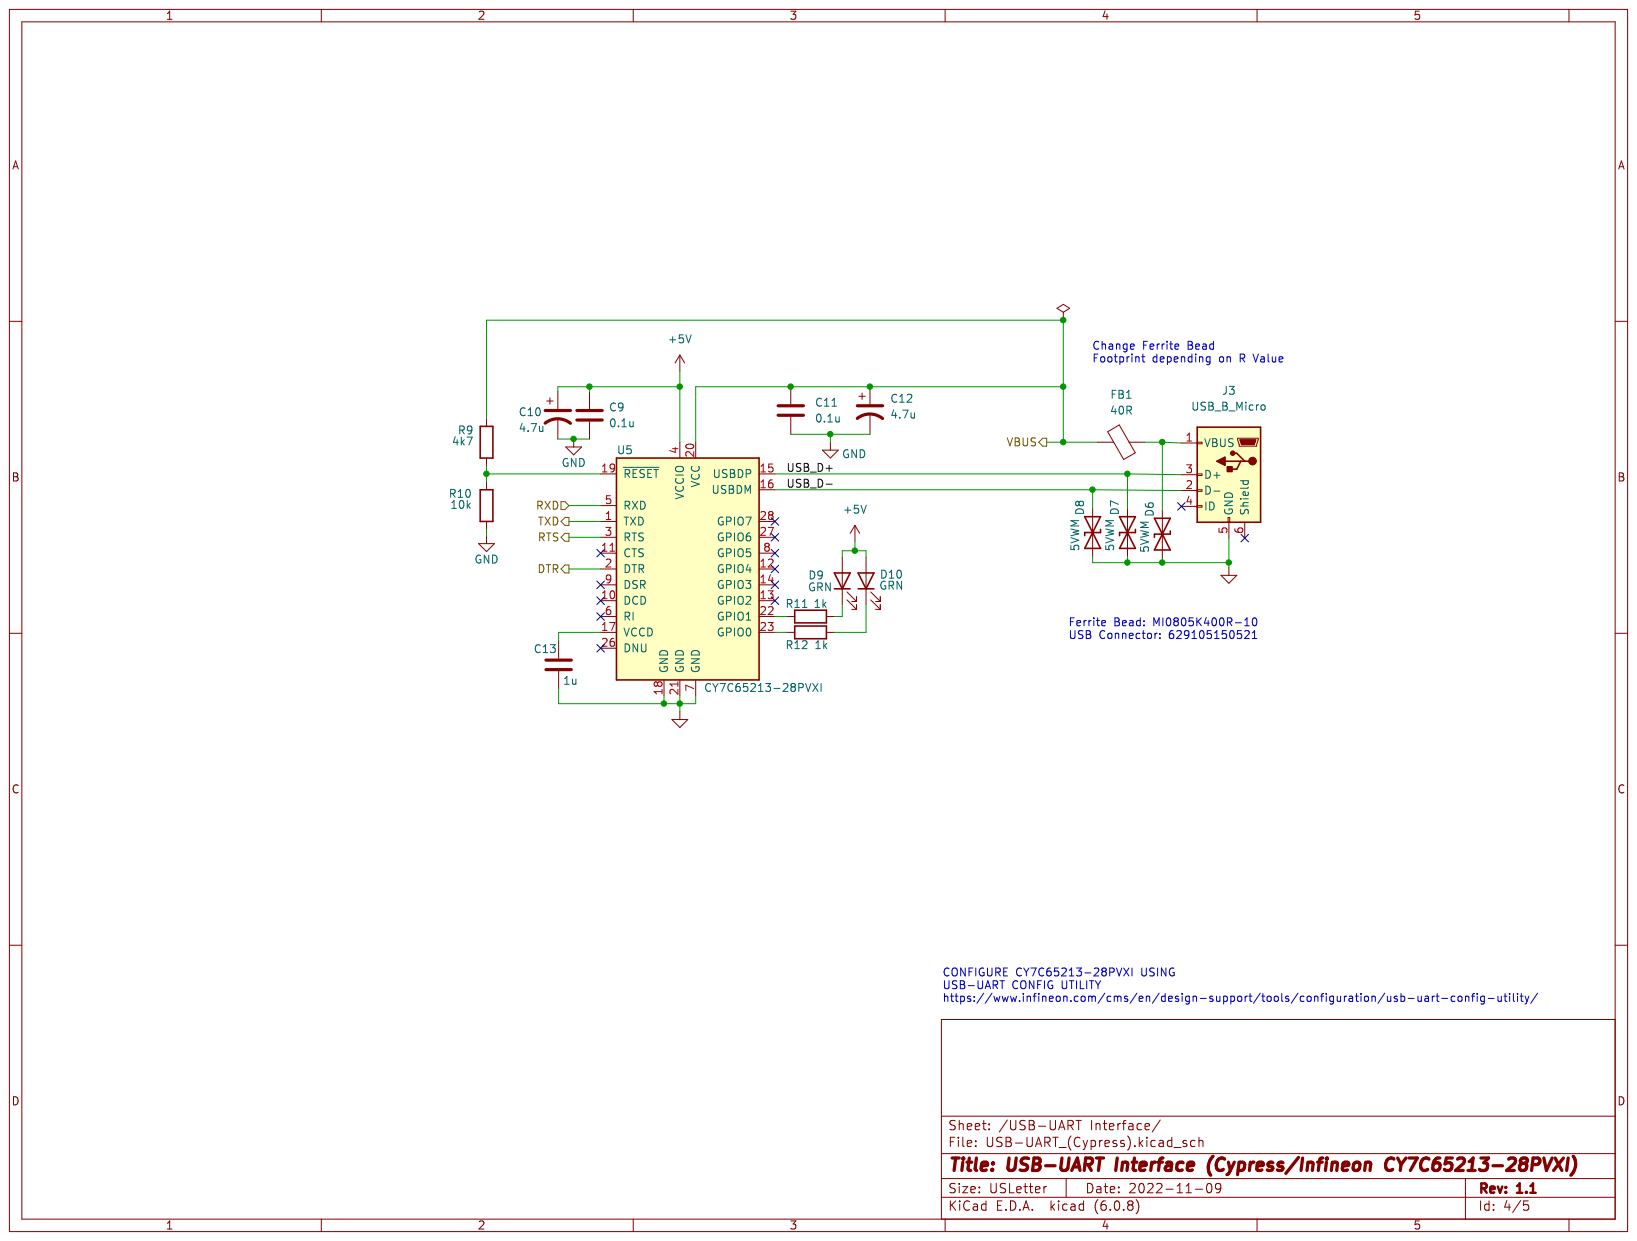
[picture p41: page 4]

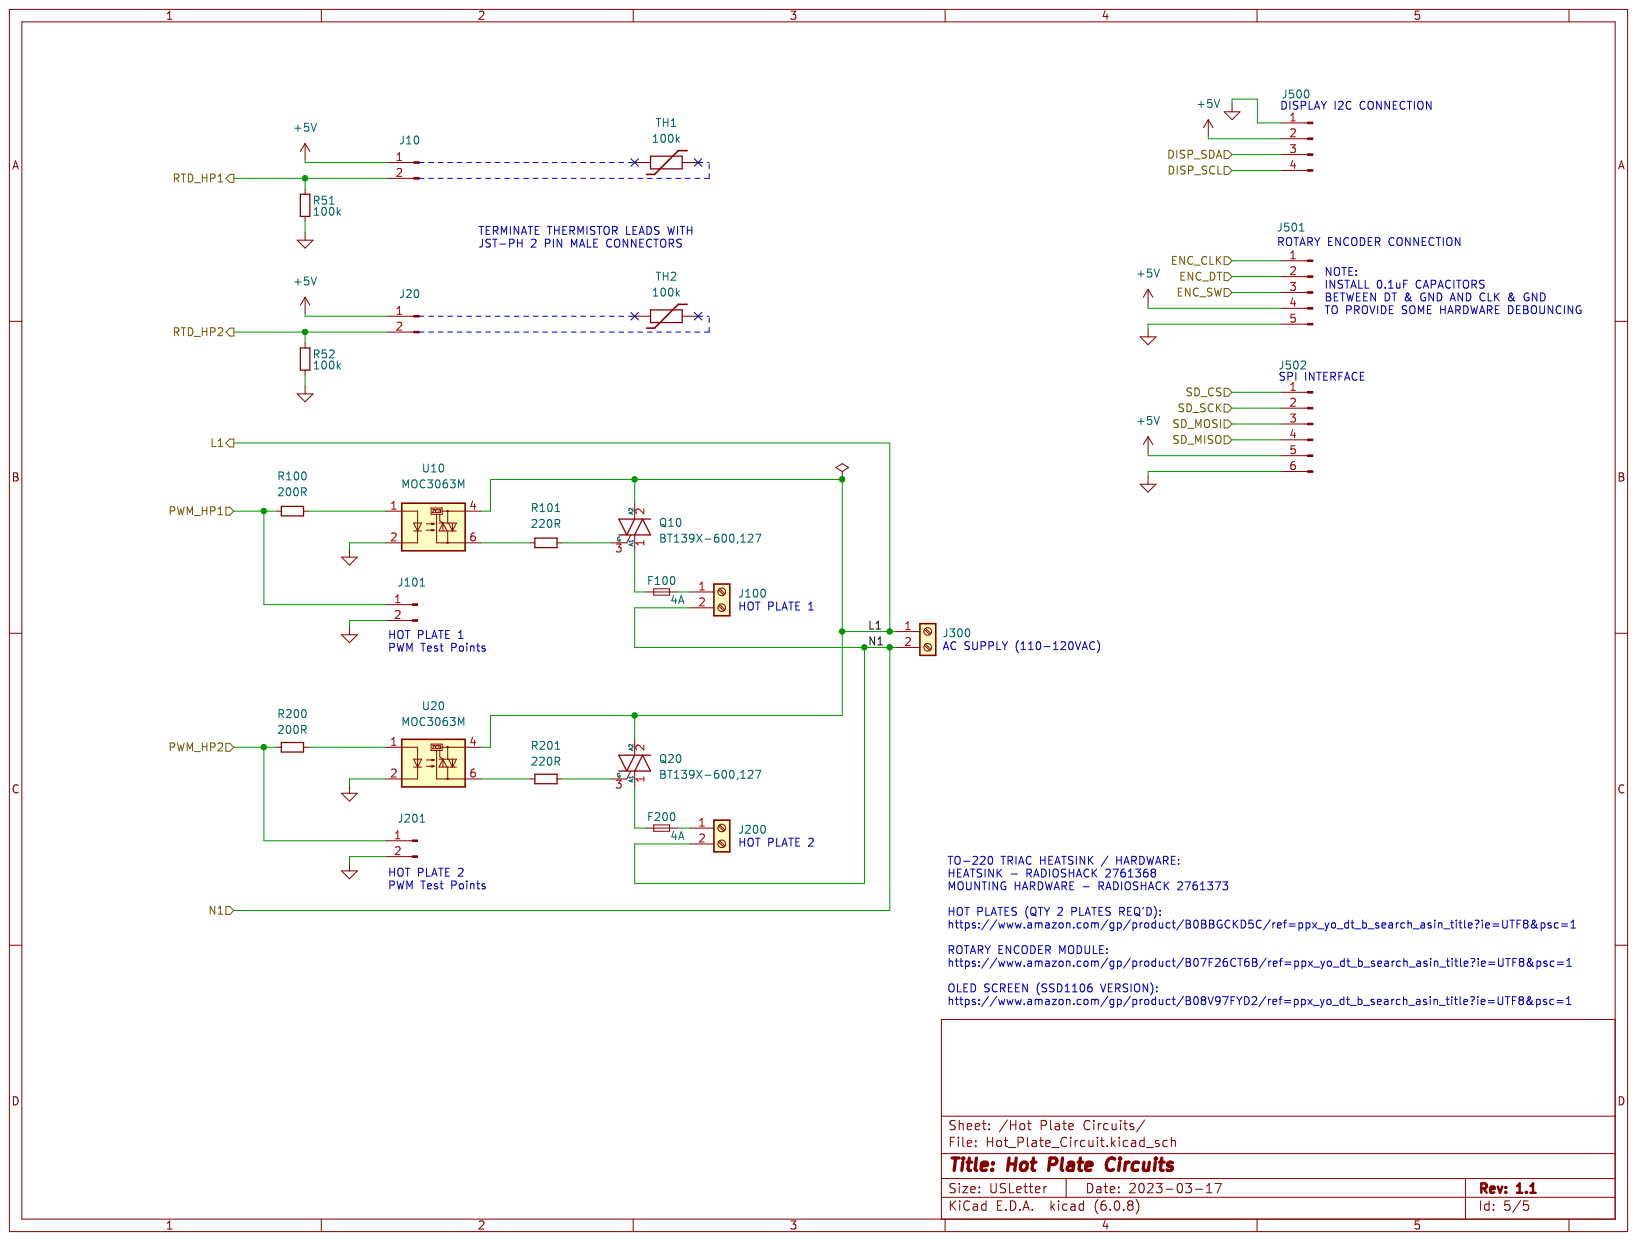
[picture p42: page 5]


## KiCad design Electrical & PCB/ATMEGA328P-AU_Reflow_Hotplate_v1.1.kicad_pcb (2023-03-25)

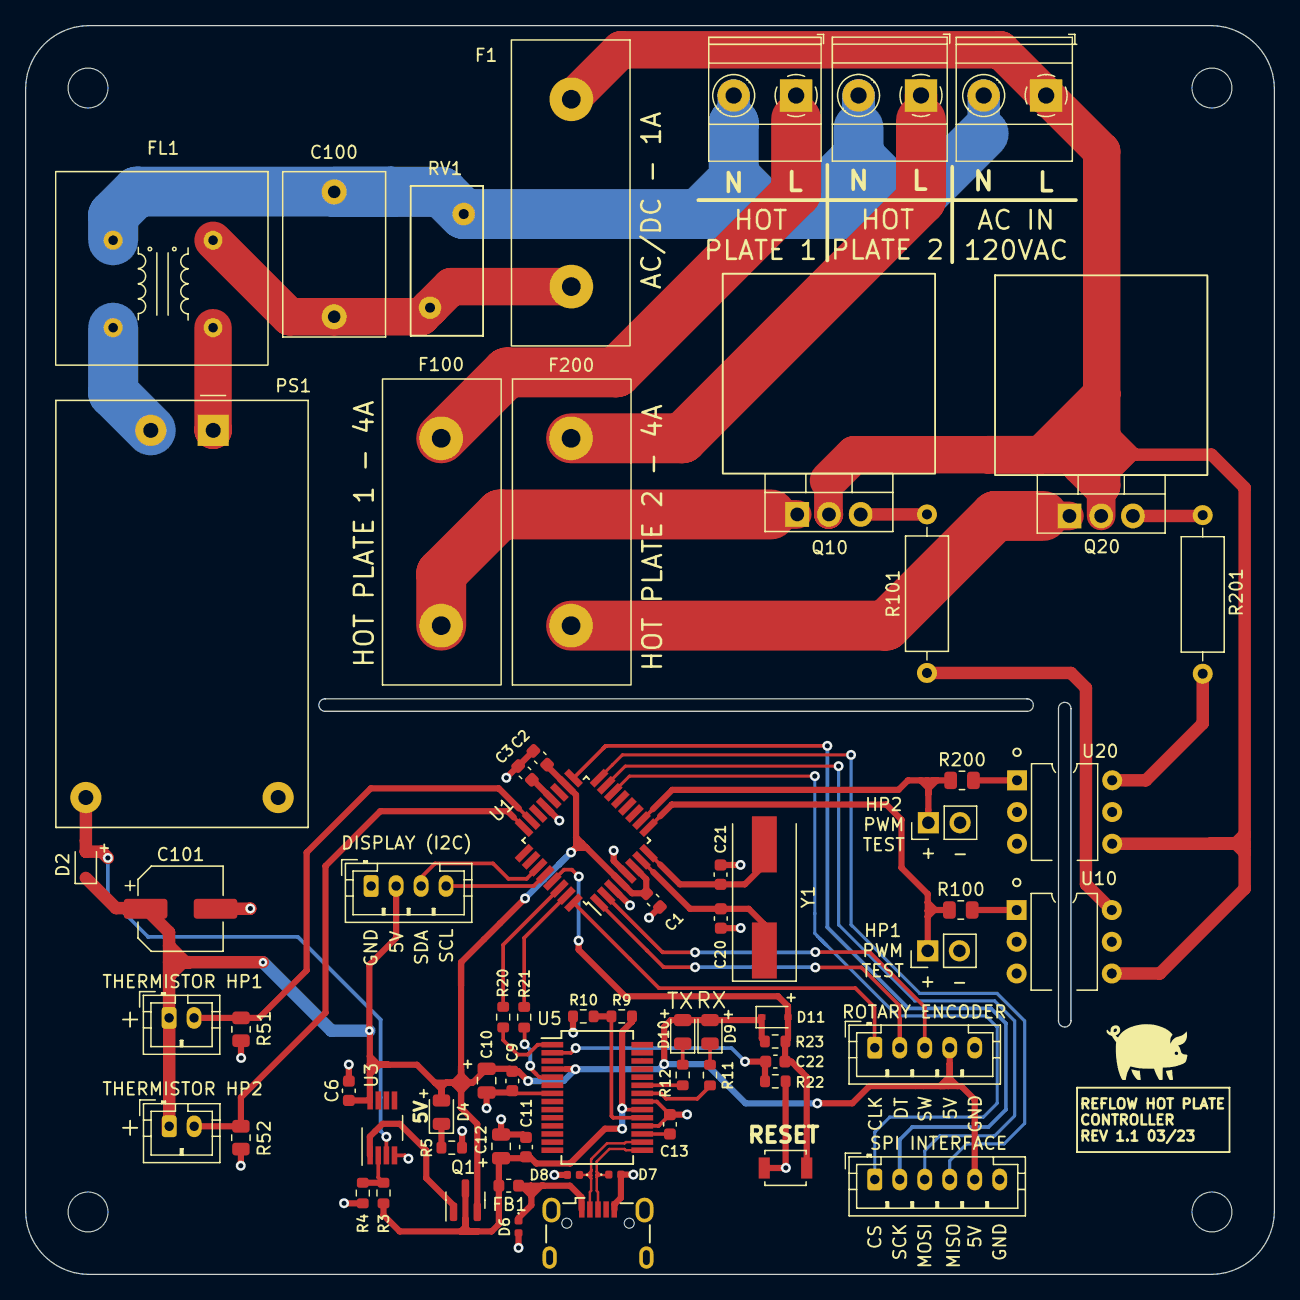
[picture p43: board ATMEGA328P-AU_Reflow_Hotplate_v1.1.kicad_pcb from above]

Board: 2 copper layers, 100.0 x 100.0 mm, 71 parts (0 on the bottom side), 53 nets.

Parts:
C1, C2, C3, C9, C11, C22: 0.1u; C_0603_1608Metric
C6: 100n; C_0603_1608Metric
C10, C12: 4.7u; C_0805_2012Metric
C13: 1u; C_0603_1608Metric
C20, C21: 22p; C_0603_1608Metric
C100: 0.1uF; C_Rect_L13.0mm_W8.0mm_P10.00mm_FKS3_FKP3_MKS4
C101: 220uF; CP_Elec_6.3x5.9
D2: BAT760,115; D_SOD-323
D4: RED; LED_0805_2012Metric
D6, D7, D8: 5VWM; D_0402_1005Metric
D9, D10: GRN; LED_0805_2012Metric
D11: 1N4148WS; D_SOD-323
F1: 1A; WE 696106003002
F100, F200: 4A; WE 696106003002
FB1: 40R; L_0603_1608Metric
FL1: 14mH; KEMET SU9H-R02140
H1, H2, H3, H4: MountingHole; MountingHole_3.2mm_M3
J3: USB_B_Micro; USB_Micro-B_Wuerth_629105150521
J10, J20: Conn_01x02_Male; JST_PH_B2B-PH-K_1x02_P2.00mm_Vertical
J100, J200, J300: 1935776; TerminalBlock_Phoenix_MKDS-1,5-2_1x02_P5.00mm_Horizontal
J101, J201: Conn_01x02_Male; PinHeader_1x02_P2.54mm_Vertical
J500: Conn_01x04_Male; JST_PH_B4B-PH-K_1x04_P2.00mm_Vertical
J501: Conn_01x05_Male; JST_PH_B5B-PH-K_1x05_P2.00mm_Vertical
J502: Conn_01x06_Male; JST_PH_B6B-PH-K_1x06_P2.00mm_Vertical
PS1: HLK-PM01; Converter_ACDC_HiLink_HLK-PMxx
Q1: DMP2110U-7; SOT-23
Q10, Q20: BT139X-600,127; TO-220-3_Vertical
R3, R4, R10, R23: 10k; R_0603_1608Metric
R5, R11, R12, R20, R21, R22: 1k; R_0603_1608Metric
R9: 4k7; R_0603_1608Metric
R51, R52: 100k; R_0805_2012Metric
R100, R200: 200R; R_0805_2012Metric
R101, R201: 220R; R_Axial_DIN0309_L9.0mm_D3.2mm_P12.70mm_Horizontal
RV1: 10D561K; RV_Disc_D12mm_W5.8mm_P7.5mm
SW1: B3U-1000P; SW_SPST_B3U-1000P
U1: ATmega328P-AU; TQFP-32_7x7mm_P0.8mm
U3: LMV358IDGKR; VSSOP-8_3.0x3.0mm_P0.65mm
U5: CY7C65213-28PVXI; SSOP-28_5.3x10.2mm_P0.65mm
U10, U20: MOC3063M; DIP-6_W7.62mm
Y1: 16MHZ; Crystal_SMD_HC49-SD

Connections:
+5V: C1.1, C2.1, C6.1, C9.2, C10.1, C101.1, D2.1 (K), D4.2 (A), D9.2 (A), D10.2 (A), D11.1 (K), J10.1, J20.1, J500.2, J501.4, J502.5, Q1.2 (S), R23.1, U1.4 (VCC), U1.6 (VCC), U1.18 (AVCC), U3.8 (V+), U5.4 (VCCIO)
/ATMega328P-AU MCU/A0: J10.2, R51.2, U1.23 (A0/PC0)
/ATMega328P-AU MCU/A1: J20.2, R52.2, U1.24 (A1/PC1)
/ATMega328P-AU MCU/A4/SDA: J500.3, U1.27 (A4/PC4)
/ATMega328P-AU MCU/A5/SCL: J500.4, U1.28 (A5/PC5)
/ATMega328P-AU MCU/AREF: C3.1, U1.20 (AREF)
/ATMega328P-AU MCU/DTR: C22.1, R22.1, U5.2 (DTR)
/ATMega328P-AU MCU/IO2: J501.1, U1.32 (INT0/IO2/PD2)
/ATMega328P-AU MCU/IO3: J501.2, U1.1 (~/INT1/IO3/PD3)
/ATMega328P-AU MCU/IO4: J501.3, U1.2 (IO4/PD4)
/ATMega328P-AU MCU/IO5: J101.1, R100.1, U1.9 (~/IO5/PD5)
/ATMega328P-AU MCU/IO6: J201.1, R200.1, U1.10 (~/IO6/PD6)
/ATMega328P-AU MCU/IO10: J502.1, U1.14 (~/IO10/PB2)
/ATMega328P-AU MCU/IO11/MOSI: J502.3, U1.15 (~/IO11/PB3)
/ATMega328P-AU MCU/IO12/MISO: J502.4, U1.16 (IO12/PB4)
/ATMega328P-AU MCU/IO13/SCK: J502.2, U1.17 (IO13/PB5)
/ATMega328P-AU MCU/RXD/IO0: R20.2, U5.1 (TXD)
/ATMega328P-AU MCU/TXD/IO1: R21.2, U5.5 (RXD)
/Hot Plate Circuits/L1: F1.1, J300.1, Q10.2 (A2), Q20.2 (A2), U10.4, U20.4
/Hot Plate Circuits/N1: C100.2, FL1.1, J100.2, J200.2, J300.2, RV1.1
/Power Supply/VBUS: C11.2, C12.1, FB1.2, Q1.3 (D), R3.1, R9.2, U5.20 (VCC)
/Power Supply/Vps: D2.2 (A), PS1.4 (+Vout), U3.3 (+)
/USB-UART Interface/USB_D+: D7.1 (A1), J3.3 (D+), U5.15 (USBDP)
/USB-UART Interface/USB_D-: D8.1 (A1), J3.2 (D-), U5.16 (USBDM)
GND: C1.2, C2.2, C3.2, C6.2, C9.1, C10.2, C11.1, C12.2, C13.2, C20.1, C21.1, C101.2, D6.2 (A2), D7.2 (A2), D8.2 (A2), J3.5 (GND), J101.2, J201.2, J500.1, J501.5, J502.6, PS1.3 (GND), R4.2, R5.2, R10.1, R22.2, R51.1, R52.1, SW1.2, U1.3 (GND), U1.5 (GND), U1.21 (GND), U3.4 (V-), U5.7 (GND), U5.18 (GND), U5.21 (GND), U10.2, U20.2
unnamed: C13.1, U5.17 (VCCD)
unnamed: C20.2, U1.7 (XTAL1/PB6), Y1.1
unnamed: C21.2, U1.8 (XTAL2/PB7), Y1.2
unnamed: C22.2, D11.2 (A), R23.2, SW1.1, U1.29 (~RESET/PC6)
unnamed: C100.1, F1.2, FL1.2, RV1.2
unnamed: D4.1 (K), R5.1
unnamed: D6.1 (A1), FB1.1, J3.1 (VBUS)
unnamed: D9.1 (K), R11.2
unnamed: D10.1 (K), R12.2
unnamed: F100.1, Q10.1 (A1)
unnamed: F100.2, J100.1
unnamed: F200.1, Q20.1 (A1)
unnamed: F200.2, J200.1
unnamed: FL1.3, PS1.1 (AC/L)
unnamed: FL1.4, PS1.2 (AC/N)
unnamed: Q1.1 (G), U3.1
unnamed: Q10.3 (G), R101.2
unnamed: Q20.3 (G), R201.2
unnamed: R3.2, R4.1, U3.2 (-)
unnamed: R9.1, R10.2, U5.19 (~RESET)
unnamed: R11.1, U5.22 (GPIO1)
unnamed: R12.1, U5.23 (GPIO0)
unnamed: R20.1, U1.30 (IO0/PD0)
unnamed: R21.1, U1.31 (IO1/PD1)
unnamed: R100.2, U10.1
unnamed: R101.1, U10.6
unnamed: R200.2, U20.1
unnamed: R201.1, U20.6

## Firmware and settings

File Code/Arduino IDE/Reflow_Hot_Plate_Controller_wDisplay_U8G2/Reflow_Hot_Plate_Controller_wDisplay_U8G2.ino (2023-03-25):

/* 
Solder Reflow Hot Plate Controller
by Ken S. (03/2023)

Code for an ATMEGA328P-AU based design for a solder reflow hot plate to be used for soldering SMD components onto custom PCBs. 
The microcontroller uses 2 PID loops to individually control the temperature for 2 aluminum heating plates. 
An OLED display and rotary encoder with push button allow the user to configure various parameters 
(reflow profile, PID tuning constants for the hot plate PID loops, etc), save the configuration to the microcontroller EEPROM memory, 
and start the unit in either constant temperature mode, or reflow profile mode.

THIS SOFTWARE IS PROVIDED ''AS IS'' AND ANY
EXPRESS OR IMPLIED WARRANTIES, INCLUDING, BUT NOT LIMITED TO, THE IMPLIED
WARRANTIES OF MERCHANTABILITY AND FITNESS FOR A PARTICULAR PURPOSE ARE
DISCLAIMED. IN NO EVENT SHALL THE AUTHOR(S) BE LIABLE FOR ANY
DIRECT, INDIRECT, INCIDENTAL, SPECIAL, EXEMPLARY, OR CONSEQUENTIAL DAMAGES
(INCLUDING, BUT NOT LIMITED TO, PROCUREMENT OF SUBSTITUTE GOODS OR SERVICES;
LOSS OF USE, DATA, OR PROFITS; OR BUSINESS INTERRUPTION) HOWEVER CAUSED AND
ON ANY THEORY OF LIABILITY, WHETHER IN CONTRACT, STRICT LIABILITY, OR TORT
(INCLUDING NEGLIGENCE OR OTHERWISE) ARISING IN ANY WAY OUT OF THE USE OF THIS
SOFTWARE, EVEN IF ADVISED OF THE POSSIBILITY OF SUCH DAMAGE.  
*/

#include <Arduino.h> 
#include <Wire.h>
#include <EEPROM.h>
#include <PID_v1.h>
#include <U8g2lib.h>

// Definitions for the rotary encoder
#define encCLK_inp 2
#define encDT_inp 3
#define encSW_inp 4
#define readCLK bitRead(PIND, 2)  //faster than digitalRead()
#define readDT bitRead(PIND, 3)   //faster than digitalRead()

// Definitions & Variables for the Thermistors
#define THERMISTORPIN1 A0          // which analog pin to connect
#define THERMISTORPIN2 A1          // which analog pin to connect
#define THERMISTORNOMINAL1 120000  // resistance at 25 degrees C
#define THERMISTORNOMINAL2 120000  // resistance at 25 degrees C
#define TEMPERATURENOMINAL1 25     // temp. for nominal resistance (almost always 25 C)
#define TEMPERATURENOMINAL2 25     // temp. for nominal resistance (almost always 25 C)
#define BCOEFFICIENT1 3950         // The beta coefficient of the thermistor (usually 3000-4000)
#define BCOEFFICIENT2 3950         // The beta coefficient of the thermistor (usually 3000-4000)
#define SERIESRESISTOR1 100000     // the value of the 'other' resistor
#define SERIESRESISTOR2 100000     // the value of the 'other' resistor
#define Numsamples 5               // how many samples1 to take and average, more takes longer but is more 'smooth'

#define pwmPin1 5  // PWM Output Pin for Hotplate 1 Control
#define pwmPin2 6  // PWM Output Pin for Hotplate 1 Control

int samples1[Numsamples];
int samples2[Numsamples];
double steinhart1 = 0.0;    // Thermistor Temperature Converted Value (deg C)
double steinhart2 = 0.0;    // Thermistor Temperature Converted Value (deg C)
double T1Disp = 0.0;        // Running T1 Temperature Display (update at running timer interval)
double T2Disp = 0.0;        // Running T2 Temperature Display (update at running timer interval)
double thermistor1Buffer = 0.0;   // Thermistor 1 temperature value buffer
double thermistor2Buffer = 0.0;   // Thermistor 2 temperature value buffer
bool thermistor1Fail = 0;   // Thermistor 1 Failure Flag
bool thermistor2Fail = 0;   // Thermistor 2 Failure Flag

// Rotary Encoder Operation Variables
volatile int tempCounter = 0;
volatile int menuCounter = 1;
int protectedMenuCounter = 1;
int previousMenuCounter = 0;
volatile int selectCounter = 0;
int protectedSelectCounter = 0;
int previousSelectCounter = 0;
bool encSW;

// Definitions for Menu Structure
uint8_t menuIndex = 0;         // Initialize to 0, or Main menu
uint8_t selectIndex = 0;       // Initialize to 0, or 1st option
uint8_t selectIndexMax = 1;    // Create variable for max selection index and initialize to 1 item
bool running = 0;              // Running state flag
bool reflowParamSelected = 0;  // Reflow menu parameter selected for edit flag
bool pidParamSelected = 0;     // PID menu parameter selected for edit flag
bool selectFlag = 0;
bool startConfirm = 0;
uint8_t curPos[2] = { 0, 0 };

// Process Variables & default values - Based upon MG Chemicals 4902P Sn42Bi57Ag1 Low Temperature Solder Paste T3
uint8_t wrkInt = 0;
double wrkDouble = 0.0;
uint8_t parametersReflow[7] = { 115, 100, 145, 155, 185, 180, 35 };  // T1, t1, T2, t2, T3, t3, Reflow Duration
double parametersPID[6] = { 3.30, 0.02, 3.45, 3.30, 0.02, 3.45 };  // Kp1, Ki1, Kd1, Kp2, Ki2, Kd2

// EEPROM Intermediate Variables
uint8_t parametersReflowREAD[7] = {0, 0, 0, 0, 0, 0, 0};
int parametersPIDREAD[6] = {0, 0, 0, 0, 0, 0};
int parametersPIDint[6] = {0, 0, 0, 0, 0, 0};

// PID Variables
double pid_Setpoint;
double pid1_Input, pid1_Output;  // Define PID Variables Loop 1
double pid2_Input, pid2_Output;  // Define PID Variables Loop 2

// Running Execution Variables
bool runningBuffer = 0;
uint8_t runningState = 0;        // States: 1 = RAMP, 2 = SOAK, 3 = REFLOW RAMP, 4 = REFLOW, 5 = COOLING / COMPLETE
unsigned long time_now = 0;
int runningSecondCounter = 0;
double initTempSnapshot = 25.0;
uint8_t constTempSP = 35;       // Constant Temp Mode Temperature SP
bool runningMode = 0;           // Run Mode variable: 0 = CONSTANT TEMP MODE, 1 = REFLOW PROFILE MODE, 


// Create PID Object(s)
PID hotPlate1PID(&pid1_Input, &pid1_Output, &pid_Setpoint, parametersPID[0], parametersPID[1], parametersPID[2], DIRECT);  // Set Proportional on Measurement (P on Error is default), and Direct acting
PID hotPlate2PID(&pid2_Input, &pid2_Output, &pid_Setpoint, parametersPID[3], parametersPID[4], parametersPID[5], DIRECT);  // Set Proportional on Measurement (P on Error is default), and Direct acting

// Create u8g2 object
U8G2_SH1106_128X64_NONAME_1_HW_I2C u8g2(U8G2_R0, /* reset=*/U8X8_PIN_NONE);

// -----------------------------------------------------------
// Interrupt handling routines for rotary encoder
// -----------------------------------------------------------
void isrEncCLK() {
  if (readDT != readCLK) {
    tempCounter++;
  } else {
    tempCounter--;
  }

  if (selectFlag == 1) {
    selectCounter += tempCounter;
  } else {
    if ((tempCounter > 0) && (menuCounter < selectIndexMax)) {
      menuCounter++;
    } else if ((tempCounter < 0) && (menuCounter > 1)) {
      menuCounter--;
    }
  }
  tempCounter = 0;
}

void isrEncDT() {
  if (readCLK == readDT) {
    tempCounter++;
  } else {
    tempCounter--;
  }

  if (selectFlag == 1) {
    selectCounter += tempCounter;
  } else {
    if ((tempCounter > 0) && (menuCounter < selectIndexMax)) {
      menuCounter++;
    } else if ((tempCounter < 0) && (menuCounter > 1)) {
      menuCounter--;
    }
  }
  tempCounter = 0;
}

// -----------------------------------------------------------
// EEPROM Read / Write handling routines
// -----------------------------------------------------------
void writeUInt8TArrayIntoEEPROM(int address, uint8_t numbers[], int arraySize) {
  int addressIndex = address;
  for (int i = 0; i < arraySize; i++) 
  {
    EEPROM.update(addressIndex, numbers[i]);   // Does not need to be bit shifted as the uint8_t data type takes only 1 byte
    addressIndex ++;
    delay(10); // delay for EEPROM
  }
}

void writeIntArrayIntoEEPROM(int address, int numbers[], int arraySize) {
  int addressIndex = address;
  for (int i = 0; i < arraySize; i++) 
  {
    EEPROM.update(addressIndex, numbers[i] >> 8);
    EEPROM.update(addressIndex + 1, numbers[i] & 0xFF);
    addressIndex += 2;
    delay(10); // delay for EEPROM
  }
}

void readUInt8TArrayFromEEPROM(int address, uint8_t numbers[], int arraySize) {
  int addressIndex = address;
  for (int i = 0; i < arraySize; i++)
  {
    numbers[i] = (EEPROM.read(addressIndex));  // Does not need to be bit shifted as the uint8_t data type takes only 1 byte
    addressIndex ++;
    delay(10);
  }
}

void readIntArrayFromEEPROM(int address, int numbers[], int arraySize) {
  int addressIndex = address;
  for (int i = 0; i < arraySize; i++)
  {
    numbers[i] = (EEPROM.read(addressIndex) << 8) + EEPROM.read(addressIndex + 1);
    addressIndex += 2;
    delay(10);
  }
}

// -----------------------------------------------------------
// Parameter Calculations
// -----------------------------------------------------------
void calcParameters() {

  if (menuIndex == 3) {     // Reflow Profile
    wrkInt = selectCounter + parametersReflow[menuCounter - 1];

    if (encSW) {
      parametersReflow[menuCounter - 1] = wrkInt;
      selectCounter = 0;
      wrkInt = 0;
      wrkDouble = 0.0;
    }
  }

  if (menuIndex == 4) {     // PID Parameters
    wrkDouble = ((float)selectCounter * 0.01) + parametersPID[menuCounter - 1];
    if (wrkDouble < 0 ) {
      wrkDouble = 0;
    }

    if (encSW) {
      parametersPID[menuCounter - 1] = wrkDouble;
      selectCounter = 0;
      wrkInt = 0;
      wrkDouble = 0.0;
    }
  }

  if (menuIndex == 98) {     // Running - Const Temp SP
    wrkInt = selectCounter + constTempSP;

    if (encSW) {
      constTempSP = wrkInt;
      selectCounter = 0;
      wrkInt = 0;
      wrkDouble = 0.0;
    }
  }
}

void pidLoop1() {
  pid1_Input = steinhart1;
  hotPlate1PID.Compute();
  analogWrite(pwmPin1, pid1_Output);
} 

void pidLoop2() {
  pid2_Input = steinhart2;
  hotPlate2PID.Compute();
  analogWrite(pwmPin2, pid2_Output);
} 

// -----------------------------------------------------------
// Display, Menu Navigation, & Encoder Selection Handling
// -----------------------------------------------------------
void updateCursorPosition() {
  int i = 0;

  switch (menuIndex) {
    curPos[0] = 0;
    curPos[1] = 0;
    case 0:  // MAIN MENU
      curPos[0] = 0;
      if (menuCounter == 1) {
        curPos[1] = 19;
      } else if (menuCounter == 2) {
        curPos[1] = 27;        
      } else {
        curPos[1] = 50; 
      }
      if (encSW) {
        if (menuCounter == 1) {           // Start Reflow Selected
          runningMode = 1;
          startConfirm = 1;
          menuIndex = 1;
        } else if (menuCounter == 2) {    // Start Const. Temp Selected
          runningMode = 0;
          startConfirm = 1;
          menuIndex = 1;
        } else if (menuCounter == 3) {
          menuIndex = 2;
        }
        menuCounter = 1;
      }
      break;
    case 1:  // CONFIRM DIALOG
      if (menuCounter == 1) {
        curPos[0] = 29;  curPos[1] = 45;
      } else {
        curPos[0] = 69;  curPos[1] = 45;
      }
      if (encSW) {
        if (menuCounter == 1) {     // ----- NO Selection -----
          if (startConfirm == 1) {  // If Start Confirm True, profile is NOT running, selecing 'NO' would fall back to main menu
            running = 0;
            menuIndex = 0;
            menuCounter = 1;
            startConfirm = 0;
          } else {                  // If Start Confirm False, profile IS running, selecing 'NO' would fall back to running screen to continue running
            running = 1;            
            if (runningMode == 1) {
              menuIndex = 99;
            } else {
              menuIndex = 98;
            }
            menuCounter = 1;
          }
        }
        if (menuCounter == 2) {     // ----- YES SELECTION -----
          if (startConfirm == 1) {  // if Start Confirm True, selecting 'Yes' would START running the profile
            running = 1; 
            if (runningMode == 1) {
              menuIndex = 99;
            } else {
              menuIndex = 98;
            }
            menuCounter = 1;
            startConfirm = 0;
          } else {                  // if Start Confirm False, profile is running. Selecting 'Yes' would STOP running the profile
            running = 0;            
            menuIndex = 0;
            menuCounter = 1;
          }
        }
      }
      break;
    case 2:  // CONFIGURATION MENU
      curPos[0] = 0;
      switch (menuCounter) {
        case 1:
          curPos[1] = 19;
          break;
        case 2:
          curPos[1] = 27;
          break;
        case 3:
          curPos[1] = 43;
          break;
        case 4:
          curPos[1] = 64;
          break;
      }
      if (encSW) {
        if (menuCounter == 4) {           // Back selection - Return to Main Menu
          menuIndex = 0;
          menuCounter = 1;
        } else {
          menuIndex = menuCounter + 2;    // Offset selection by 2
          menuCounter = 1;
        }
      }
      break;
    case 3:  // REFLOW PROFILE
      if ((menuCounter < 8 && menuCounter % 2 == 1) || menuCounter == 8) {
        curPos[0] = 0;
      } else if (menuCounter < 8 && menuCounter % 2 == 0) {
        curPos[0] = 66;
      }
      switch (menuCounter) {
        case 1: curPos[1] = 19; break;  // T1
        case 2: curPos[1] = 19; break;  // t1
        case 3: curPos[1] = 29; break;  // T2
        case 4: curPos[1] = 29; break;  // t2
        case 5: curPos[1] = 39; break;  // T3
        case 6: curPos[1] = 39; break;  // t3
        case 7: curPos[1] = 49; break;  // Reflow Duration
        case 8: curPos[1] = 64; break;  // Back
      }
      if (encSW) {
        if (menuCounter == 8) {
          menuIndex = 2;                // Return to Config Menu
          menuCounter = 1;
        } else {
          selectFlag = !selectFlag;
        }
      }
      break;
    case 4:  //  PID Loop Tuning
      switch (menuCounter) {
          case 1:  curPos[0] = 0;  curPos[1] = 19; break;  // Kp1
          case 2:  curPos[0] = 0;  curPos[1] = 29; break;  // Ki1
          case 3:  curPos[0] = 0;  curPos[1] = 39; break;  // Kd1
          case 4:  curPos[0] = 66; curPos[1] = 19; break;  // Kp2
          case 5:  curPos[0] = 66; curPos[1] = 29; break;  // Ki2
          case 6:  curPos[0] = 66; curPos[1] = 39; break;  // Kd2
          case 7:  curPos[0] = 0;  curPos[1] = 64; break;  // Back
      }
      if (encSW) {
        if (menuCounter == 7) {
          menuIndex = 2;              // Return to Config Menu
          menuCounter = 1;
        } else {
          selectFlag = !selectFlag;
        }
      }
      break;
    case 5:   //  Save Configuration
      writeUInt8TArrayIntoEEPROM(1, parametersReflow, 7);   // Write Reflow Paramter Data to EEPROM
      for (i = 0; i < 6; i++) {                             // Convert PID paramters to INT for storage
        parametersPIDint[i] = parametersPID[i] * 100;
      }
      writeIntArrayIntoEEPROM(8, parametersPIDint, 6);      // Write PID Parameter Data to EEPROM
      delay(3000);
      menuIndex = 2;                  // Return to Config Menu
      menuCounter = 1;
      break;
    case 98:  //  Running - Constant Temp Mode
      curPos[0] = 0; 
      if (menuCounter == 1) {
        curPos[1] = 48;
      } else {
        curPos[1] = 64;
      }
      if (encSW) {
        if (menuCounter == 2) {
          startConfirm = 0;
          menuIndex = 1;
          menuCounter = 1;
        } else {
          selectFlag = !selectFlag;
        }
      }   
      break;
    case 99:  //  Running - Reflow Profile Mode
      curPos[0] = 0;
      curPos[1] = 56;
      if (encSW) {
        startConfirm = 0;
        menuIndex = 1;
        menuCounter = 1;
      }    
      break;
  }
}
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
void loop() {
  // ----------------------------------------
  // Rotary encoder handling
  // ----------------------------------------

  // Poll the encoder pushbutton switch. Delay for minor debounce effect.
  if (!digitalRead(encSW_inp)) {
    encSW = 1;
    delay(100);
  } else {
    encSW = 0;
  }

  // Handle rotary encoder rotation
  noInterrupts();
  protectedMenuCounter = menuCounter;
  interrupts();
  previousMenuCounter = protectedMenuCounter;

  // Handle parameter modifications
  if (selectFlag == 1) {
    calcParameters();
  }

  // Display Handling
  updateCursorPosition();
  updateDisplay();

  // Initialize Running State to 1 (RAMP) when profile run is started
  if (running == 1 && runningBuffer == 0) {   
    runningSecondCounter = 0;
    readThermistor();
    initTempSnapshot = (steinhart1 + steinhart2) / 2; // Capture initial temperature as average between the 2 thermistors
    runningState = 1;
  }

  // Additional logic when not running - Force PID loops to Manual mode, read thermistor every 10 sec for 'Hot' menu display and thermistor fail check
  if (!running) {
    
    pid_Setpoint = 0;                 // Force PID values to 0 / Manual & force a 0 output on PWM output pins
    hotPlate1PID.SetMode(MANUAL);
    hotPlate2PID.SetMode(MANUAL);
    pid1_Output = 0;
    pid2_Output = 0;
    analogWrite(pwmPin1, 0);
    analogWrite(pwmPin2, 0);

    if(millis() - time_now > 10000){   // 10 Second timer - Read thermistors every 10 sec when not running for 'HOT' menu display.
        time_now = millis();           // Also increment thermistor fail counters and set fail flag(s) if 3 identical readings are encountered
        readThermistor();
    }
    
    initTempSnapshot = 0;             // Clear / reset intial temp snapshot value
  } 
  
  // Call running state logic to execute SP calculation and PID loop execution
  if (running == 1 && runningMode == 1) {
    reflowRunning();
  } else if (running == 1 && runningMode == 0) {
    constTempRunning();
  }

  // Buffer running flag
  runningBuffer = running;  
}

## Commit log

2023-03-26 Update to README
    Update to readme to highlight ground lead attachment to hot plate. It was indicated in assembly drawing but deserved highlighted attention in the readme documentation
2023-05-03 Added library files to electrical / PCB project directory
